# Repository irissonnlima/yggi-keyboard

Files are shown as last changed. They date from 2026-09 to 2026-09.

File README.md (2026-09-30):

<p align="center">Marca do Yggi</p>

# Yggi Keyboard

**Um teclado split ortholinear que vira column stagger com um clique.** Open hardware e open source.

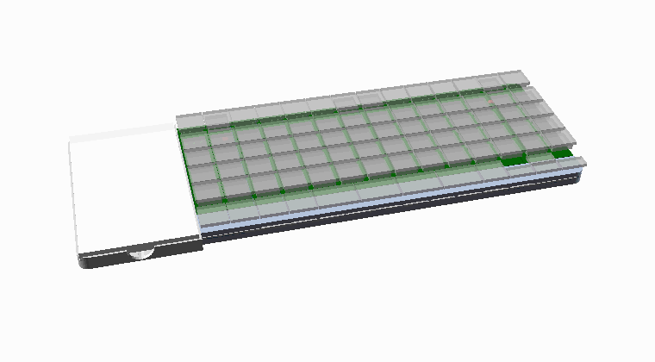
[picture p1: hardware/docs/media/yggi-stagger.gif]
Yggi indo de ortholinear para column stagger


O nome é uma homenagem a Yggdrasil, a árvore que liga os nove mundos da mitologia nórdica. O objetivo de longo prazo é que o Yggi seja o centro que liga os seus computadores e periféricos.

## Conceito de design

> Imagens de conceito para guiar o visual do produto. O projeto técnico (medidas, mecanismo, placas) está em [`hardware/`](hardware/).

**Ortholinear e column stagger.** Em cima, o teclado fechado: um retângulo perfeito, com a baia do e-reader à esquerda. Embaixo, as colunas destravadas e deslizadas no stagger: as colunas externas e a fileira do polegar ficam fixas.

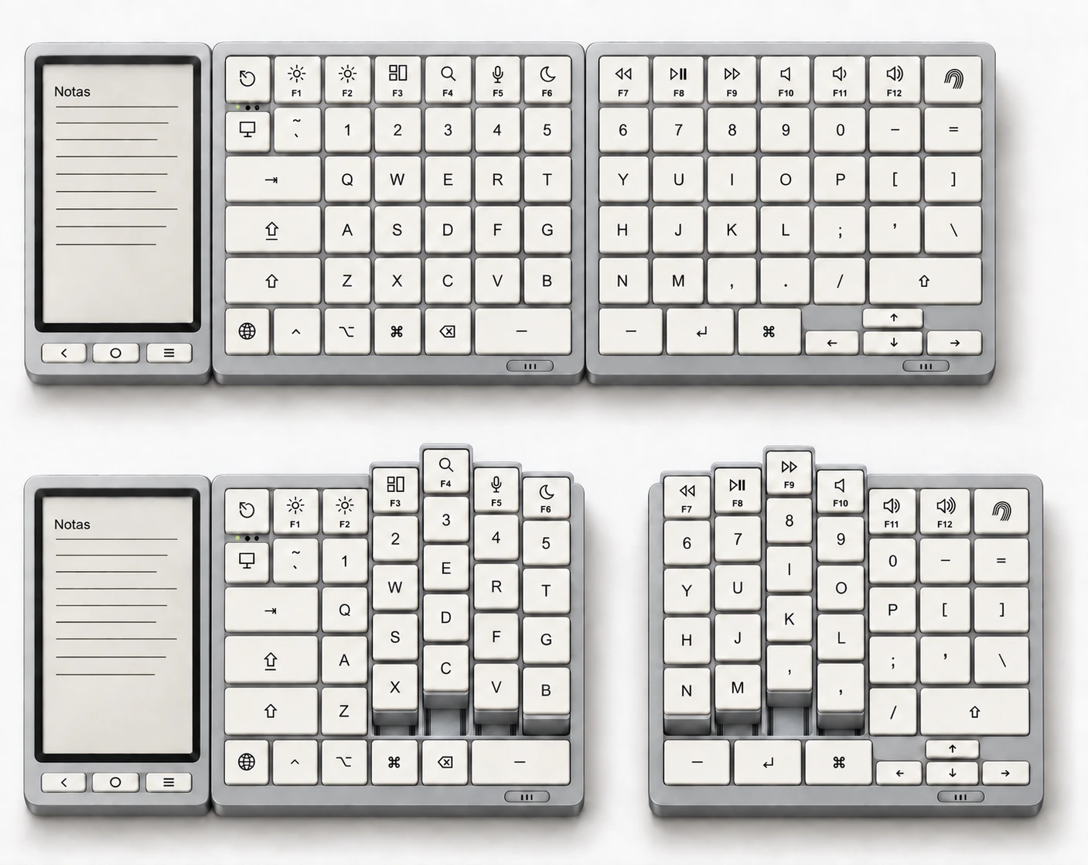
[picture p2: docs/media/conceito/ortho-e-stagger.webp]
Yggi em ortholinear e em column stagger


**Colunas que deslizam inteiras.** Cada coluna corre sobre trilhos, e o vão que ela deixa fica aparente e acabado, sem moldura solta.

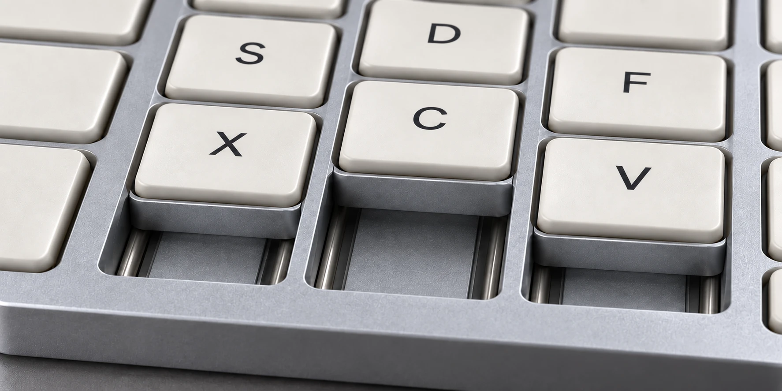
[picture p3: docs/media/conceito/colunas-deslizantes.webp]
Colunas deslizantes sobre trilhos


**E-reader destacável e conectores.** O e-reader tem tela e-ink, três botões, apoio de mesa e USB-C próprio. Ele encaixa na lateral do teclado por uma fileira de contatos pogo, com ímãs acima e abaixo.

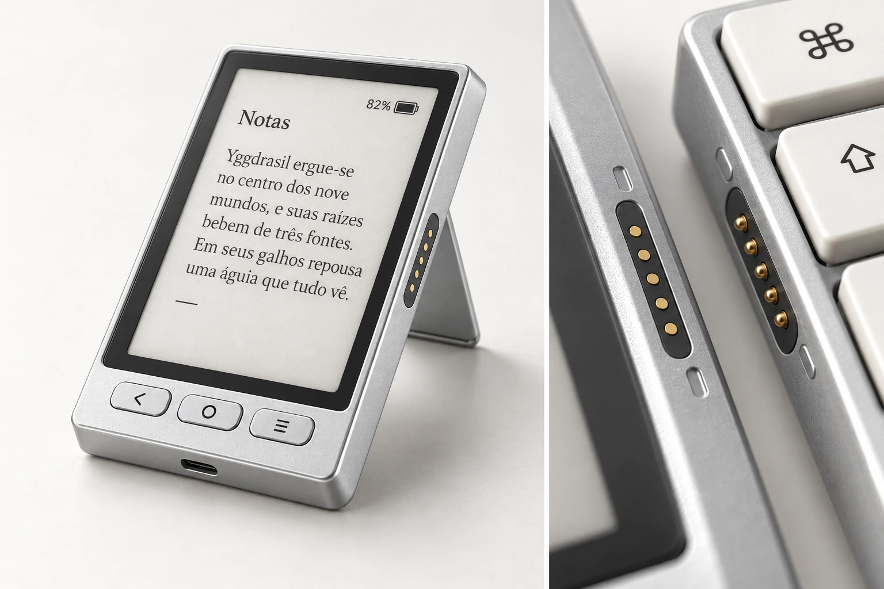
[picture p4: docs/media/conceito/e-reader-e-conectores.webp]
E-reader destacável e conectores pogo


## Marca

Três barrinhas iguais em Y, na simetria isométrica (120° entre elas): os dois braços são as metades do teclado e a haste é o tronco que liga tudo, como a Yggdrasil. Os arquivos estão em [`docs/brand/`](docs/brand/): [marca](docs/brand/yggi-marca.svg), [marca branca](docs/brand/yggi-marca-branca.svg), [assinatura](docs/brand/yggi-assinatura.svg) e [ícone do app](docs/brand/yggi-icone.svg).

Na barra de menus do Mac, o ícone é o próprio teclado em miniatura, visto de cima: as colunas sobem conforme o stagger abre (de 0 a 100%), as metades se afastam quando estão separadas, e o ícone fica apagado quando o teclado está desconectado. Clicar nele abre o balão com os widgets.

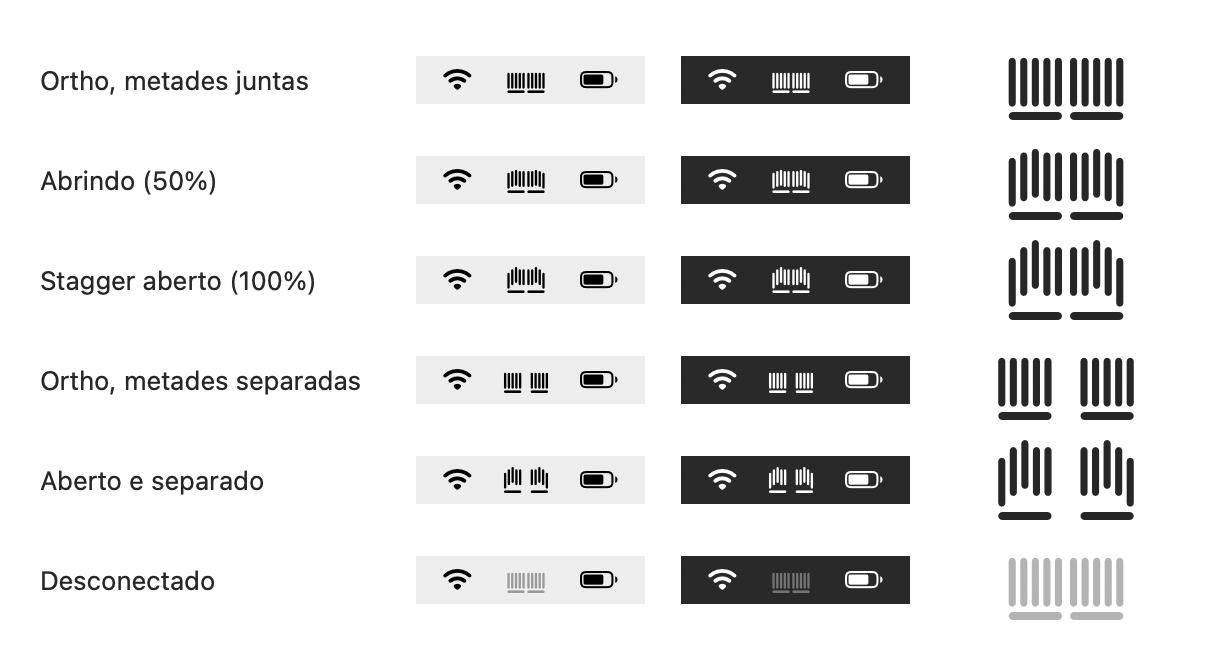
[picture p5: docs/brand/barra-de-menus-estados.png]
Ícone da barra de menus em cada estado


## Onde está cada coisa

| Pasta | O que tem |
|---|---|
| [`hardware/`](hardware/) | mecanismo de stagger (CAD), placas de circuito, layout das teclas, simulação interativa |
| [`app/`](app/) | app do computador: núcleo em Rust + interface macOS em SwiftUI ([como rodar](app/README.md)) |
| [`docs/`](docs/) | documentação do produto: [funcionalidades](docs/funcionalidades.md), [app](docs/app.md), [arquitetura e testes](docs/arquitetura.md), marca e imagens de conceito |

Ainda virá `firmware/` (ZMK + módulos Yggi).

## Fases

1. **Teclado Bluetooth** com o mecanismo de stagger.
2. **E-reader destacável** que encaixa no teclado.
3. **Hub**: mouse, trackpad e áudio passando pelo Yggi.

**[▶ Simulação interativa](https://htmlpreview.github.io/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)**

## Licença

A definir. Sugestão: **CERN-OHL-S-2.0** para o hardware e **MIT** para firmware e software.

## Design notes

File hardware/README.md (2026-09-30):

# Yggi Keyboard · hardware

**Um teclado split ortholinear que vira column stagger com um clique.** Open hardware e open source.

Yggi indo de ortholinear para column stagger

Em ortholinear, as duas metades formam um retângulo perfeito, como um teclado comum. Aperte o botão ao lado dos LEDs e uma mola faz as colunas deslizarem inteiras até o stagger escolhido (50, 100 ou 150%). Para voltar, empurre as colunas até ouvir o clique.

O nome é uma homenagem a Yggdrasil, a árvore que liga os nove mundos da mitologia nórdica. O objetivo de longo prazo é que o Yggi seja o centro que liga os seus computadores e periféricos.

**[▶ Abrir a simulação interativa](https://htmlpreview.github.io/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)** ([arquivo](docs/simulacao.html)): vista de cima com antes e depois, corte lateral, **raio-x dos circuitos** (as 5 placas em cadeia, jumpers, MCU, bateria, USB-C, ímãs e pogo), diagrama das ligações e o ciclo da mola em corte.

---

## Estado atual

| | |
|---|---|
| **Fase** | 1 · teclado Bluetooth com mecanismo de stagger |
| **CAD** | [`stagger-mechanism/yggi_v3.scad`](stagger-mechanism/yggi_v3.scad) (OpenSCAD, paramétrico) |
| **Layout** | [`layout/yggi-v9-B-ortho.json`](layout/yggi-v9-B-ortho.json) (Keyboard Layout Editor) |
| **Verificado** | todas as peças compilam; nenhuma colisão entre peças em 0, 50, 100 e 150% |
| **Ainda não testado** | nada foi impresso ou montado |

| Ortholinear (0%) | Column stagger (150%) |
|---|---|
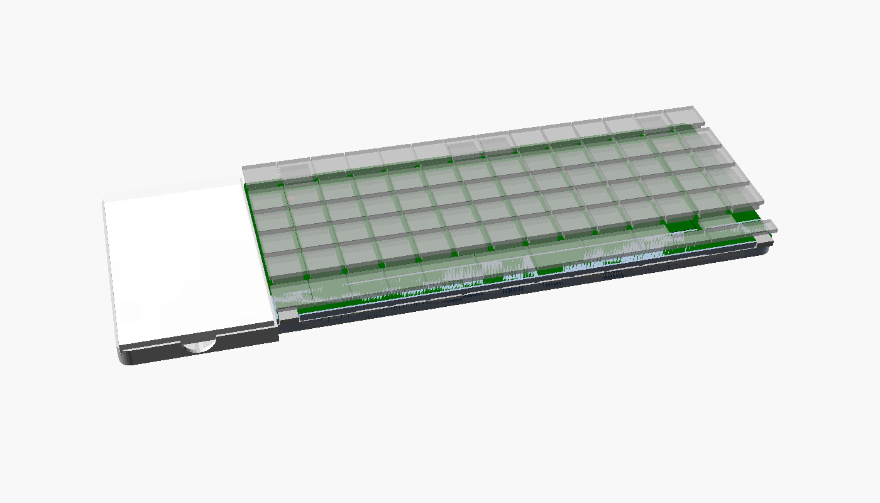
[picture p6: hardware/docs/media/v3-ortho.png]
ortho
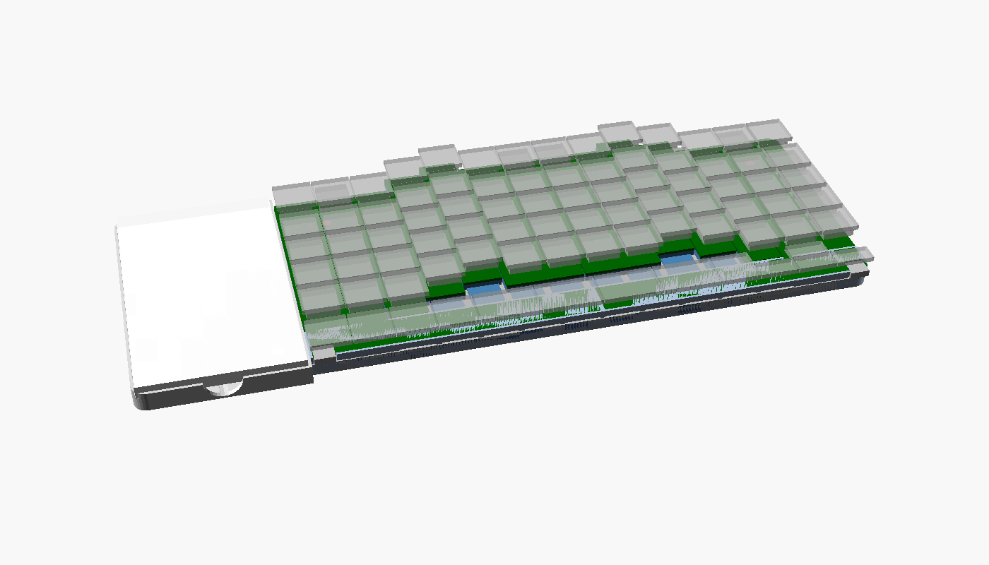
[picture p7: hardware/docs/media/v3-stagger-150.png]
stagger
|  |  |

**Vista lateral** (inclinação de 5° dada pela cunha da bateria):

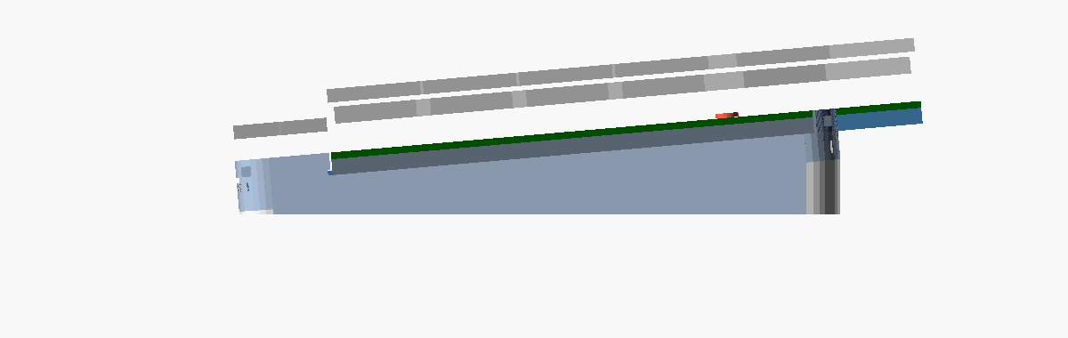
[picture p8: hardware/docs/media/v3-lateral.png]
lateral


**Metade esquerda explodida** (cunha com bateria, bandeja, placa-came, chassi, colunas com as suas placas, bloco fixo, placa L e barra do polegar; na rev1, a placa MCU fica na cunha, ao lado da bateria: veja [`pcb/rev1.md`](pcb/rev1.md)):

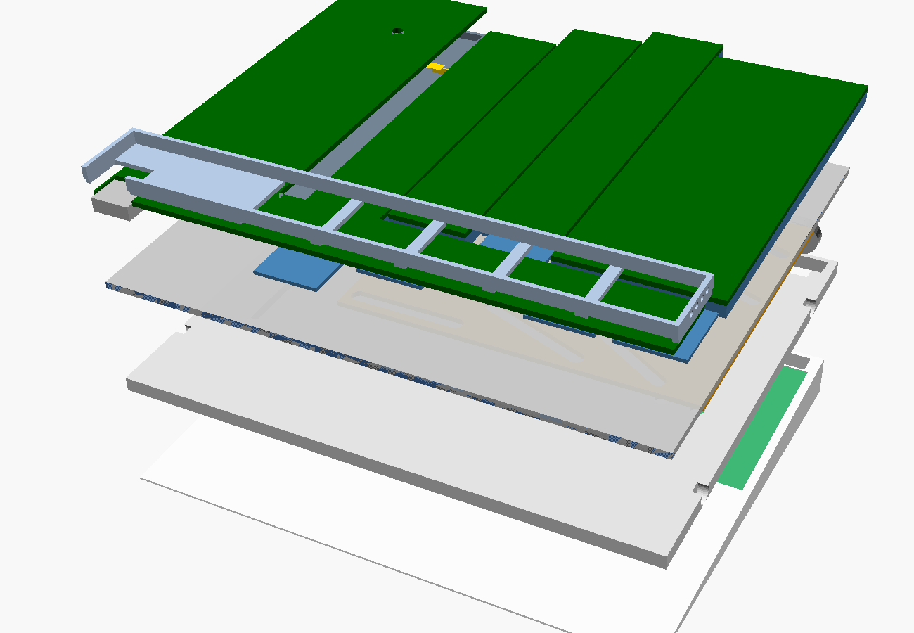
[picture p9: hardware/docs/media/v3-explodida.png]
explodida


**Placas de circuito** ([detalhes](pcb/README.md)): as 6 placas das duas mãos (placa L com o bloco fixo e a barra do polegar, coluna 1u e coluna 2u), geradas com Ergogen e roteadas no KiCad, com LED RGB por tecla:

placas

---

## Layout

Split 7 + 7 colunas com layout Mac, 79 teclas, mais uma baia para um e-reader destacável.

- **2 colunas externas fixas de cada lado:** esc, a **tecla Yggi** (troca de computador) com **3 LEDs** que indicam o aparelho, `` ` ``, e tab, caps e shift de 2u.
- **Colunas móveis:** mindinho, anelar, médio e indicador. Cada uma sobe o quanto o dedo precisa: médio +15 mm, anelar e indicador +9 mm, mindinho 0.
- **Barra do polegar fixa:** fn ⌃ ⌥ ⌘ ⌫ ␣ | ␣ ↩ ⌘ e setas de 0,5u, no estilo Magic Keyboard.
- **Baia de 4u × 6,5u** para um e-reader do tamanho do XTeink X4 (69 × 114 mm).

**Tecla Yggi:** toque vai para o próximo computador pareado. Segurar + 1…5 vai direto para um computador. Segurar 3 s entra em pareamento. A troca só acontece ao soltar a tecla, então um toque acidental não muda nada.

---

## Como o mecanismo funciona

Cada metade, de baixo para cima:

1. **Cunha** (impressa): cria a inclinação de 5° e guarda a **bateria**, o tambor da **mola** e o curso da **trava**.
2. **Bandeja**: bolsão da placa-came, canal da fita da mola e dos fios, lingueta da trava e furos do batente.
3. **Placa-came** (chapa de 1,2 mm): tem 8 rasgos inclinados, 2 por coluna móvel. Ao deslizar 24 mm em X, empurra cada coluna em Y na proporção do rasgo. A posição dos pinos foi escolhida por busca para os rasgos nunca se cruzarem (folga mínima de 9 mm).
4. **Chassi imutável** (chapa de 1,6 mm): rasgos-guia em Y. Fica sempre escondido embaixo das colunas.
5. **Gavetas**: cada coluna móvel é um trenó impresso com **a sua própria placa de circuito** em cima (switches Choc montados direto na placa). As placas se ligam **em cadeia**, de uma coluna para a vizinha, por um jumper flexível que atravessa as paredes na faixa entre a fileira F e a dos números. Dois pinos-parafuso por gaveta fazem o papel de guia, came e trava contra levantar. A **saia** da frente sai de baixo da barra do polegar e tampa o vão quando a coluna sobe.
6. **Bloco fixo** e **barra do polegar**: não se movem.

**Mola e trava:**
- Uma **mola de força constante** (fita de aço, tipo trena) puxa a placa-came para o stagger o tempo todo.
- Em ortho, uma **lingueta** com dente entra num furo da placa e segura tudo.
- O **botão** ao lado dos LEDs empurra o dente para baixo, e a mola leva as colunas até o **pino de batente** (50, 100 ou 150%, trocável por baixo).
- Para voltar, é só empurrar as colunas. Os rasgos são inclinados o bastante (~32°) para o movimento voltar pela came, e o dente estala de volta no furo.

**Módulos:** as faces de encaixe são retas, com ímãs de 4 × 2 mm e um **conector pogo magnético de 5 pinos** (VBUS, GND, 2 de dados e detecção) na face da bandeja. As bordas externas são arredondadas. Com as metades juntas, um único USB-C carrega tudo. Separadas, cada metade funciona sozinha por Bluetooth.

---

## Eletrônica

| | |
|---|---|
| **Placas por metade** | **5, em cadeia**: placa L (bloco fixo + barra do polegar) → coluna 1u → coluna 1u → coluna 1u → coluna 2u. As 3 de 1u são **idênticas**, graças a um barramento rotativo. |
| **Microcontrolador** | um **nRF52840** (módulo Raytac MDBT50Q) por metade, numa **placa MCU própria na cunha**, sob o bloco fixo, com a antena na borda externa. Junto ficam o carregador, a chave dos LEDs e o **USB-C, na face de trás da cunha**. Um flex de 20 vias liga a placa MCU à placa L. Na rev0 das placas, o MCU é externo (nice!nano ligado por fios). Plano: [`pcb/rev1.md`](pcb/rev1.md). |
| **Por que nRF52840** | é o chip mais bem suportado pelo ZMK. Tem 21 GPIO, o suficiente para a matriz 6 × 7 mais os 3 LEDs. |
| **Firmware** | [ZMK](https://zmk.dev) (Zephyr, MIT): Bluetooth, split sem fio, 5 perfis de computador, bateria. Funções do Yggi (tecla de troca, LEDs, conversa com o e-reader) entram como **módulos ZMK** próprios. |
| **Bateria** | LiPo de 4 mm na cunha, ~1800 mAh por metade (76 × 46 mm). A cunha comporta células maiores se a inclinação aumentar. |
| **Ligação das colunas** | **jumper de 13 vias** (5 linhas, 5 colunas, VLED, GND e dados dos LEDs) entre placas vizinhas. Colunas vizinhas andam no máximo 9 mm uma em relação à outra no perfil padrão; o projeto aceita até 15 mm. Protótipo: fios de silicone. Produto: jumper flexível (FPC). |
| **Switches** | Choc V1 com **furos passantes** (soldados ou em soquetes Mill-Max). O soquete hot-swap Kailh não cabe numa coluna de 17,4 mm. As 4 setas de meia altura (mão direita) usam chave tátil SMD (TS-1187A). |
| **Iluminação** | **LED RGB por tecla** (SK6812MINI-E, montado por baixo, brilhando pela janela do Choc): 38 na mão esquerda e 35 na direita, em cadeia de uma placa para a seguinte. Mais os 3 LEDs de aparelho da tecla Yggi. |

O **e-reader** (fase 2) tem cérebro próprio. A base sugerida é o firmware open source [CrossPoint](https://github.com/crosspoint-reader/crosspoint-reader) (ESP32). Encaixado, ele mostra o estado do teclado. Solto, é um leitor.

---

## Estrutura da pasta `hardware/`

```
docs/
  simulacao.html          simulação interativa: vista de cima, corte, raio-x e mola
  media/                  GIF e imagens do README
pcb/
  ergogen/generate.py     gera as placas (Ergogen)
  route.py                termina as placas no KiCad (LEDs, diodos, trilhas pelo Freerouting, DRC)
  assemble.py             junta as 10 placas num arquivo só, para ver o teclado inteiro
  kicad/                  as 6 placas (placa L, coluna 1u, coluna 2u; esquerda e _dir) e teclado_*.kicad_pcb
  outlines/               contornos de corte (.dxf)
stagger-mechanism/
  yggi_v3.scad            CAD atual (mecanismo fino, inclinado, com mola)
  yggi_v2.scad            versão anterior (histórico)
  yggi_stagger.scad       primeiro protótipo, 5 colunas (histórico)
  renders/                imagens geradas pelo OpenSCAD
layout/
  yggi-v9-B-*.json        layout atual para o Keyboard Layout Editor
tools/
  make_gif.py             junta os PNGs do OpenSCAD num GIF (sem dependências)
  pcb_preview.py          prévia SVG das placas a partir dos arquivos do KiCad
```

## Como abrir e gerar

Os comandos abaixo rodam de dentro da pasta `hardware/`.

**CAD:** instale o [OpenSCAD](https://openscad.org) (versão *snapshot*) e abra `yggi_v3.scad`. Em **Window → Customizer** dá para mexer em `stagger_pct`, `stop_pct`, `explode`, `joined` e `show_internals`.

```bash
brew install --cask openscad@snapshot
```

**Exportar uma peça em STL:**

```bash
openscad -D 'part="cam_plate"' -o placa-came.stl stagger-mechanism/yggi_v3.scad
```

**Verificar colisões:** a opção `part="check"` com `check=...` mostra a interseção entre duas peças. Resultado vazio significa sem colisão.

```bash
openscad --backend=manifold -D 'part="check"' -D 'check="gav_chassis"' -D 'stagger_pct=150' -o /tmp/c.stl stagger-mechanism/yggi_v3.scad
```

**Refazer o GIF:**

```bash
for p in 0 25 50 75 100 125 150; do openscad -D "stagger_pct=$p" -D 'stop_pct=150' --camera=90,45,0,55,0,-15,600 --imgsize=760,420 --colorscheme=Tomorrow -o "/tmp/f$p.png" stagger-mechanism/yggi_v3.scad; done
```

```bash
python3 tools/make_gif.py docs/media/yggi-stagger.gif /tmp/f0.png /tmp/f25.png /tmp/f50.png /tmp/f75.png /tmp/f100.png /tmp/f125.png /tmp/f150.png --pingpong
```

---

## Roteiro

1. **Fase 1 · teclado:** imprimir e testar o mecanismo (bandeja, placa-came, chassi e 2 gavetas primeiro), depois firmware ZMK e placas de circuito por gaveta.
2. **Fase 2 · e-reader destacável:** tela, estado do teclado, leitura.
3. **Fase 3 · hub:** mouse, trackpad e áudio passando pelo Yggi.

**Pendências conhecidas:**
- Rev1 da placa L: módulo nRF52840, carregador, USB-C nas duas mãos, chave dos LEDs RGB e **conector pogo magnético de 5 pinos** (VBUS, GND, 2 de dados e detecção), no lugar dos 4 pogo + ímãs soltos.
- Fixação das placas: 1 parafuso M2 por coluna na faixa entre F e números + presilhas no trenó; M2 na placa L.
- Keycap de 0,5u para as setas táteis.
- Estabilizadores das teclas de 2u.
- Escolher a mola de força constante e a bateria reais.
- Testar folgas e a força da trava na prática.

## Licença

A definir. Sugestão: **CERN-OHL-S-2.0** para o hardware e **MIT** para o firmware, a mesma do ZMK.

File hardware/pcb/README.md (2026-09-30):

# Placas de circuito do Yggi (rev0)

Prévia das placas

Cada mão usa **5 placas em cadeia**:

```
placa L  ──►  coluna 1u  ──►  coluna 1u  ──►  coluna 1u  ──►  coluna 2u
(MCU)         (mindinho)      (anelar)        (médio)         (indicador)
```

São **6 projetos** no total, 3 por mão:

| Placa | Esquerda | Direita |
|---|---|---|
| **Placa L** (bloco fixo + barra do polegar, fixa, com o MCU) | esc, Yggi, `` ` ``, tab, caps e shift de 2u; barra com fn, ⌃, ⌥, ⌘, ⌫ e espaço | 8 teclas de 1u (F12, lock, `-`, `=`, `[`, `]`, `'`, `\`) e shift de 2u; barra com espaço, return, ⌘ e 4 setas de meia altura |
| **Coluna 1u** (×3 por mão, **idênticas**) | `coluna_1u` | `coluna_1u_dir` |
| **Coluna 2u** (indicador, fim da cadeia) | `coluna_2u` | `coluna_2u_dir` |

As placas das colunas da direita são as da esquerda com a posição espelhada: a entrada do jumper fica do lado direito. Os switches não são espelhados.

Cada tecla Choc tem um **LED RGB** (SK6812MINI-E). As **setas** da mão direita têm meia altura e o Choc não cabe nelas, então usam uma **chave tátil SMD** (XKB TS-1187A, 5,1 × 5,1 mm) sob um keycap de 0,5u. As setas não têm LED.

As placas saem em duas etapas:
1. O [Ergogen](https://ergogen.xyz) posiciona switches, diodos e pads a partir de [`ergogen/generate.py`](ergogen/generate.py).
2. O [`route.py`](route.py) termina cada placa no KiCad: diodos SOD-123, LEDs RGB, setas táteis, regras da JLCPCB, trilhas pelo [Freerouting](https://github.com/freerouting/freerouting) e DRC.

Os resultados ficam versionados:

| Arquivo | O que é |
|---|---|
| [`kicad/*.kicad_pcb`](kicad/) | as 6 placas roteadas para o KiCad 10, com DRC limpo (0 violações, 0 ligações faltando) |
| [`kicad/teclado_*.kicad_pcb`](kicad/) | **só para ver**: as 10 placas do teclado juntas, na posição do CAD (`teclado_150`: stagger 150%; `teclado_0`: ortho), afastadas para ver onde cada uma acaba. Os jumpers aparecem como linhas de ligação. Gerado por [`assemble.py`](assemble.py) |
| [`kicad/*.kicad_pro`, `*.kicad_dru`](kicad/) | regras de projeto: trilha 0,25, isolamento 0,2, via 0,6/0,3, borda 0,5 mm (0,2 mm só nos pads do LED RGB, que ficam junto do próprio recorte) |
| [`outlines/*.dxf`](outlines/) | contornos de corte, os mesmos usados no CAD |
| [`preview.svg`](preview.svg) | a prévia acima (`python3 hardware/tools/pcb_preview.py`) |

## A ligação em cadeia

Cada placa se liga à vizinha por um **jumper flexível de 13 vias**, que atravessa as paredes das colunas na **faixa livre entre a fileira F e a dos números** (y = 87,25 mm no CAD). É o único corredor sem switches ao longo de toda a coluna.

As colunas vizinhas andam uma em relação à outra quando o stagger muda. Com o perfil padrão em 150%, a diferença é:

| Ligação | Movimento relativo |
|---|---|
| placa L → mindinho | 0 mm |
| mindinho → anelar | 9 mm |
| anelar → médio | 6 mm |
| médio → indicador | 6 mm |

O jumper e os rasgos nas paredes foram dimensionados para **até 15 mm**, então qualquer perfil de placa-came funciona.

- **Protótipo:** 13 fios de silicone 30 AWG, soldados nos pads.
- **Produto:** jumper em placa flexível (FPC) de pé, com 1,6 mm de altura, dobrado em S.

### Barramento rotativo: por que as 3 placas de 1u são iguais

Os dois blocos de pads têm 2 × 7 posições (passo 1,27 mm), na mesma ordem. Dois blocos lado a lado não cabem na coluna de 17,4 mm. Por isso o **J_IN** (entrada) fica 1,6 mm mais para trás e à esquerda, e o **J_OUT** (saída) 1,6 mm mais para a frente e à direita. O jumper liga o J_OUT de uma placa ao J_IN da seguinte, 10,82 mm ao lado. Na mão direita, é o espelho.

| Posição | 1 | 2 | 3 | 4 | 5 | 6 | 7 |
|---|---|---|---|---|---|---|---|
| **J_IN**, linha de cima | R0 | R1 | R2 | R3 | R4 | VLED | GND |
| **J_IN**, linha de baixo | C1 | C2 | C3 | C4 | C5 | — | DIN |
| **J_OUT**, linha de cima | R0 | R1 | R2 | R3 | R4 | VLED | GND |
| **J_OUT**, linha de baixo | C2 | C3 | C4 | C5 | — | — | DOUT |

Cada placa **usa a coluna C1** e repassa as outras deslocadas uma posição. Na placa seguinte, o que era C2 chega como C1, e assim por diante. Por isso a mesma placa serve em qualquer posição da cadeia. A coluna 2u usa C1 e C2 e não tem saída.

Os **dados dos LEDs** entram em DIN, passam pelos LEDs da placa, um depois do outro, e saem em DOUT, na mesma posição do bloco seguinte. VLED e GND passam direto.

### Matriz (uma mão)

**6 linhas × 7 colunas = 13 pinos do MCU**, mais 1 para os LEDs RGB e, na esquerda, 3 para os LEDs da tecla Yggi.

| Linha | Esquerda | Direita |
|---|---|---|
| R0 | fileira F | fileira F |
| R1 | números (inclui a tecla Yggi) | números |
| R2, R3, R4 | letras (tab, caps e shift de 2u em COL0) | letras (shift de 2u em COL0) |
| R5 | barra do polegar (toda na placa L) | barra: espaço COL6, return COL5, ⌘ COL4, ← COL3, ↑ COL2, ↓ COL1, → COL0 |

| Coluna | Onde fica |
|---|---|
| COL0, COL1 | bloco fixo, na placa L |
| COL2 | 1ª placa de 1u (mindinho) |
| COL3 | 2ª placa de 1u (anelar) |
| COL4 | 3ª placa de 1u (médio) |
| COL5, COL6 | placa 2u (indicador) |

Diodos no sentido **COL2ROW**, o padrão do ZMK: coluna → switch → diodo → linha.

### Posição das peças em cada tecla Choc

| Peça | Onde | Face |
|---|---|---|
| LED RGB SK6812MINI-E | 4,7 mm ao sul do centro, na janela do LED do Choc V1, brilhando por um recorte na placa | baixo (montagem invertida) |
| Diodo 1N4148W (SOD-123) | canto noroeste, 3,6 mm à esquerda e 4,5 mm ao norte, na vertical | baixo |

Na barra do polegar os switches ficam girados 180°, e tudo gira junto.

## Decisões e limites da rev0

- **Sem soquete hot-swap Kailh.** O soquete passa ~0,9 mm da borda de uma coluna de 17,4 mm e bateria na parede do trenó. As placas usam os **furos passantes do Choc**: dá para soldar o switch ou usar **soquetes Mill-Max** (tubinhos dentro do furo) e manter a troca de switches.
- **MCU externo na rev0.** Cada placa L tem um **cabeçalho de pads**. Na esquerda são 20: GND, VLED, DIN, R0–R5, COL0–COL6, LED1–3 e GND. Na direita são 17, sem os LEDs da tecla Yggi. Na bancada, ele se liga por fios a uma placa nRF52840 (nice!nano). O VLED vem do VCC chaveado do nice!nano.
- **Na rev1** a eletrônica vai para uma **placa MCU própria na cunha** (módulo nRF52840, carregador, USB-C atrás, chave dos LEDs RGB), ligada à placa L por um flex de 20 vias, mais o conector pogo magnético de 5 pinos, os estabilizadores de 2u e a fixação com M2. Plano completo e posições no CAD: [`rev1.md`](rev1.md).
- **Espessura:** o CAD usa placa de **1,2 mm**. Encomendar com 1,2 mm, ou ajustar `pcb_t` no CAD para 1,6.
- **Trilhas traçadas pelo Freerouting**, em 2 camadas, e conferidas pelo DRC do KiCad. O traçado é automático (funciona, mas não é o mais bonito). O barramento rotativo obriga as trilhas a trocar de face na faixa entre F e números: J_IN e J_OUT têm a mesma ordem, deslocada, e isso não cabe numa face só.
- **LEDs RGB (SK6812MINI-E):** um por tecla Choc, 38 na mão esquerda e 35 na direita. Cuidados:
  - cada LED gasta **~1 mA mesmo apagado** (~75 mA por mão). Por isso a energia deles precisa ser cortada quando estiverem desligados: o VCC chaveado do nice!nano na rev0 e um MOSFET na rev1;
  - em branco total, cada LED puxa até 60 mA, o que dá mais de 2 A por mão. O **brilho precisa ser limitado no firmware**, e as trilhas de 0,25 mm e os fios de 30 AWG do jumper não aguentam o brilho máximo;
  - o SK6812 foi feito para 3,7–5,5 V. No VCC de 3,3 V do nice!nano ele funciona, mas o azul e o branco ficam mais fracos;
  - a posição da janela do LED (4,7 mm ao sul) segue os projetos de referência com Choc V1. **Conferir com um switch na mão** antes de fabricar;
  - os pads do LED ficam a 0,25 mm do canto do recorte, como no footprint oficial do KiCad. O mínimo de borda da placa fica em 0,2 mm, e a regra em `*.kicad_dru` volta a exigir 0,5 mm de todo o resto;
  - um capacitor de 4,7 µF por placa, entre VLED e GND.
- **Setas táteis (direita):** XKB TS-1187A na face de cima, com o diodo embaixo. A altura e o curso são diferentes dos do Choc, então o keycap de 0,5u precisa ser desenhado para elas.
- **Diodos SOD-123 na face de baixo** (1N4148W). O `route.py` troca o diodo do Ergogen, que tem pads nas duas faces e furos passantes, por um SMD simples: fácil de soldar à mão e montável pela JLCPCB.
- **Barra do polegar com os switches girados 180°.** Com o pino 2 virado para trás, o anel dele ficava a 0,28 mm da borda de trás da barra (abaixo do mínimo da JLCPCB). Virado, fica a 0,58 mm da borda da frente. O keycap do Choc é simétrico, então nada muda para quem digita.
- **LEDs da tecla Yggi** (só na esquerda): 3 LEDs 0805 na face de cima, na faixa entre F e números (CAD x = 4, 9 e 14 mm), cada um com um resistor 0805 de 1 kΩ embaixo, no mesmo lugar. Ligação: pino LEDn do MCU → resistor → LED → GND (acende com o pino em nível alto).
- **Furo do botão da trava** (CAD 22; 87,25, espelhado na direita): o `route.py` põe uma área proibida de 2,1 mm de raio em volta dele, e outra em volta de cada recorte de LED RGB, porque o Freerouting não aplica a folga de borda aos recortes internos.
- **Ainda não tem:** furos de fixação (M2 na faixa + presilhas no trenó), os recortes dos estabilizadores de 2u e os pads do flex. Tudo isso entra na rev1 ([`rev1.md`](rev1.md)).

## Como regenerar

Precisa do KiCad 10 (`brew install --cask kicad`), do Java (`brew install openjdk`) e do [Freerouting 2.4.1](https://github.com/freerouting/freerouting/releases) em `~/.local/share/freerouting/` (ou na variável `FREEROUTING`). A partir da raiz do repositório:

```bash
python3 hardware/pcb/ergogen/generate.py
```

```bash
(cd hardware/pcb/ergogen && for d in coluna_1u coluna_2u placa_L coluna_1u_dir coluna_2u_dir placa_L_dir; do npx ergogen@4.2.1 $d.yaml -o output/$d && cp output/$d/outlines/board.dxf ../outlines/$d.dxf; done)
```

```bash
/Applications/KiCad/KiCad.app/Contents/Frameworks/Python.framework/Versions/Current/bin/python3 hardware/pcb/route.py
```

```bash
python3 hardware/pcb/assemble.py && python3 hardware/pcb/assemble.py 0
```

```bash
python3 hardware/tools/pcb_preview.py hardware/pcb/preview.svg hardware/pcb/kicad/placa_L.kicad_pcb hardware/pcb/kicad/coluna_1u.kicad_pcb hardware/pcb/kicad/coluna_2u.kicad_pcb hardware/pcb/kicad/coluna_2u_dir.kicad_pcb hardware/pcb/kicad/coluna_1u_dir.kicad_pcb hardware/pcb/kicad/placa_L_dir.kicad_pcb
```

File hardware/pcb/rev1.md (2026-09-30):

# Rev1 das placas · plano

> **Status:** arquitetura decidida e já refletida no CAD (`yggi_v3.scad`, sem colisões em 0 e 150%). As placas da rev1 ainda não foram desenhadas no KiCad.

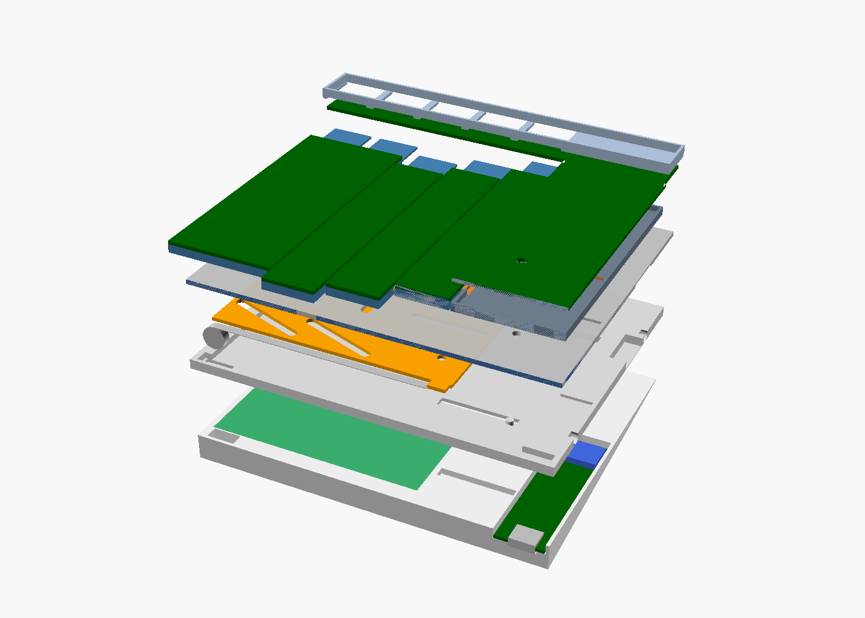
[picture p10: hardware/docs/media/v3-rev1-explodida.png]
Metade esquerda explodida, com a placa MCU na cunha


A rev0 tem as 6 placas roteadas, com LED RGB por tecla e o MCU externo (um nice!nano ligado por fios). A rev1 coloca a eletrônica dentro do teclado, numa **placa MCU própria na cunha**, e resolve a fixação das placas.

## Decisões

| Assunto | Decisão | Por quê |
|---|---|---|
| Teclas de 2u | **com estabilizador** | sem ele, tab, caps e shift balançam nas pontas |
| Onde fica o MCU | **placa MCU própria na cunha**, sob o bloco fixo | com os estabilizadores, a placa L não tem mais lugar para o módulo: entre o estabilizador (x ≈ 6,1) e o switch (x = 18) sobram 2 mm, e embaixo da barra há só 1,8 mm de altura |
| Antena | **na borda externa** da placa MCU, cercada de plástico | melhor que a posição antiga, no meio da placa L. A bateria fica longe (x ≥ 48). Recomendo a placa-came em FR4, não em aço |
| USB-C | **na face de trás da cunha**, direto na placa MCU | é a parte mais alta da cunha (~9 mm), e o USB não precisa passar pelo flex. Na frente da barra, ele batia no pino central do switch do fn |
| Placa L ↔ placa MCU | **flex de 20 vias** (passo 0,5 mm) por um rasgo no bloco fixo, no chassi e na bandeja | as duas placas são fixas. O único corredor livre fica em x < 12,5, antes do bolsão da placa-came |
| Conector entre as mãos e com a baia | **pogo magnético de 5 pinos**, na face da bandeja | a barra tem só 3 mm de altura (z 6–9), e o conector tem ~4 mm. Os 4 pogo antigos saem |
| Fixação | **1 M2 por coluna na faixa entre F e números + presilhas no trenó**; M2 na placa L | ver abaixo |

## Onde fica cada coisa (quadro da metade esquerda do CAD)

| Peça | Posição | Variável no CAD |
|---|---|---|
| Placa MCU (1,0 mm) | x 1,5–18,5; y 46–106,5 (até a face de trás); topo em z −2,5, peças viradas para cima | `MCUB` |
| Raytac MDBT50Q (10,6 × 15,6 × 2,2 mm) | x 1,8–17,4; y 49–59,6, deitado em x, com a **antena na ponta de x = 1,8** | `MOD` |
| USB-C mid-mount | x 4,5–13,5, na borda de trás da placa MCU | `USBC` |
| Rasgo do flex | x 1,5–13; y 68,6–70 (entre a tecla tab e o LED RGB da tecla de números de fora) | `FLEX` |
| Conector magnético (outra mão) | face interna da bandeja, na ponta da barra, centro em y = 9, z 0,3–4,3 | `MAGC`, `MAGC_Y[0]` |
| Conector magnético (baia, só na esquerda) | face externa da bandeja, centro em y = 32,25 | `MAGC_Y[1]` |
| Fios da bateria | canal na cunha, da bateria (x = 48) até a placa MCU | — |

A cunha tem 4,5 mm de altura na frente da placa MCU (y = 46) e 9,3 mm atrás. A placa fica num bolsão de 3,7 mm, aberto na face de trás para o USB-C.

## O que vai em cada placa

**Placa L (rev1):** igual à rev0, trocando o cabeçalho do nice!nano pelos **pads do flex de 20 vias**, e com os furos M2 e os recortes dos estabilizadores. Os 20 sinais do flex:

| Sinais | Quantos |
|---|---|
| R0–R5, COL0–COL6 (matriz) | 13 |
| DIN, VLED, GND (LEDs RGB) | 3 |
| LED1–LED3 (tecla Yggi; na direita ficam livres) | 3 |
| GND extra | 1 |

**Placa MCU (nova, uma por mão):**

```
USB-C VBUS ──►|── VIN ──► carregador (MCP73831, 500 mA) ──► BAT ──► nRF VDDH (REG0 → 3,3 V)
conector VBUS ─────┘                                          └─► load switch ──► VLED (LEDs RGB)
```

- **MDBT50Q** com a área sem cobre da antena (12,4 mm de largura, em todas as camadas) na borda.
- **Sem regulador externo:** o nRF52840 aceita a bateria direto no VDDH (2,5–5,5 V), e o regulador interno gera os 3,3 V.
- **Um USB-C carrega as duas mãos:** o VBUS passa pelo conector magnético. Um diodo Schottky em cada USB-C impede que uma mão alimente o USB-C da outra.
- **LEDs RGB pela bateria (3,5–4,2 V), com load switch e limite de corrente** (ex.: SY6280, EN em 3,3 V): corta os ~75 mA que os LEDs gastam parados e protege as trilhas e o flex. O dado de 3,3 V funciona com o LED em 4,2 V (VIH ≈ 2,9 V).
- Proteção ESD no USB, resistores de 5,1 kΩ nos CC, divisor para medir a bateria, pads de SWD (gravar o bootloader no módulo novo) e de reset, pads da bateria (célula com proteção embutida) e conector do flex.

## Pinos do nRF52840 (por mão)

| Função | Pinos | Esquerda | Direita |
|---|---|---|---|
| Matriz | 6 linhas + 7 colunas | 13 | 13 |
| Dados dos LEDs RGB | 1 | 1 | 1 |
| LEDs da tecla Yggi | 3 | 3 | — |
| Liga/desliga dos LEDs RGB | 1 | 1 | 1 |
| Nível da bateria (analógico) | 1 | 1 | 1 |
| Conector com a outra mão (2 de dados + detecção) | 3 | 3 | 3 |
| Conector da baia (2 de dados + detecção) | 3 | 3 | — |
| **Total de GPIO** (o MDBT50Q tem 48) | | **25** | **19** |

## Conector magnético de 5 pinos

| Pino | Função |
|---|---|
| 1 | VBUS (carga compartilhada) |
| 2 | GND |
| 3 | dados A |
| 4 | dados B |
| 5 | detecção (encaixado ou não) |

Os dados servem para o split com fio quando as mãos estão encaixadas (**confirmar** o suporte atual do ZMK) ou para conversar com o e-reader. O tamanho em `MAGC` (16,5 × 4 × 6 mm) é estimado: **ajustar quando a peça for escolhida**. Os fios vão do conector até a placa MCU por dentro da bandeja e da cunha.

## Fixação

- **Colunas:** 1 parafuso M2 por coluna na faixa entre F e números (a cabeça fica visível no vão entre os keycaps), mais presilhas impressas no trenó que prendem as pontas da placa. Os blocos do jumper vão ceder ~4,5 mm de largura na faixa, então os pads serão reorganizados.
- **Placa L:** M2 nos cantos do bloco fixo e na barra, entre as teclas.
- **Placa MCU:** 2 M2 na cunha.

## Falta fechar

1. **Modelo do estabilizador de 2u** (medidas dos recortes na placa L). As placas da rev0 não têm esses recortes.
2. **Peças exatas na LCSC:** USB-C mid-mount, conector magnético, conector do flex, load switch e diodos. Todas precisam caber nos 3,7 mm do bolsão.
3. **Split com fio pelo conector:** confirmar no ZMK. Se não houver suporte, os 2 pinos de dados ficam para o e-reader e para uso futuro.
4. **Onde prender os fios** do conector magnético até a placa MCU (canal na bandeja).

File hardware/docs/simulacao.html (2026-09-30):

# Yggi Keyboard · simulação

Split ortholinear que vira column stagger. Mecanismo v3: gavetas deslizantes sobre um chassi imutável, placa-came com mola, cunha traseira com bateria e baia para o e-reader.

## 1 · Vista de cima: antes e depois

Arraste o stagger. As 2 colunas externas de cada lado e a barra do polegar não se movem; as outras colunas deslizam inteiras e a saia (tracejada) tampa o vão.

Stagger0% animar

Encaixe do e-readerà esquerdano centroAparelho123

## 2 · Corte lateral: v2 × v3

A v3 fica fina porque a placa de circuito de cada coluna é o próprio plate, e placa-came e chassi são chapas finas. As placas se ligam em cadeia, de coluna em coluna, na faixa entre a fileira F e a dos números. A bateria vai numa cunha atrás e dá a inclinação.

Versãov2v3Stagger

## 3 · Raio-x de cima: circuitos e conexões

Cinco placas por metade, ligadas em cadeia: a placa L (bloco fixo + barra do polegar, com o MCU) → três colunas de 1u idênticas → a coluna dupla do indicador. Cada ligação é um jumper de 10 vias que atravessa as paredes na faixa entre a fileira F e a dos números, e se curva quando as colunas vizinhas andam diferente. Toque numa peça para ver o que é.

colunas (trenós) placas jumpers da cadeia MCU, bateria, USB-C ímãs e pogo placa-came mola e trava

Toque numa peça para ver o nome e a função.

Stagger100%Módulosencaixadosseparados

## 4 · Como os circuitos se ligam

Uma metade do teclado. Setas tracejadas = jumpers que se curvam quando as colunas andam.

## 5 · Mola: soltar e travar

Corte lateral no mesmo estilo da seção 2, passando pela trava. Embaixo, a placa-came vista de cima com a mola. O botão empurra o dente da trava para baixo, a mola puxa a placa e as colunas sobem até o batente. Empurrando as colunas de volta, o dente estala no furo e trava.

apertar o botão empurrar as colunas de volta Batente50%100%150%

Yggi Keyboard · open hardware (CERN-OHL-S sugerida) · CAD em hardware/stagger-mechanism/yggi_v3.scad

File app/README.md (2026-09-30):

# Yggi · app do computador

App do teclado Yggi: estado (computador ativo, baterias, conexão, stagger, e-reader), luzes de cada tecla, estatísticas de digitação e, depois, o editor de teclas. Hoje roda no **macOS**, com um **teclado simulado**, porque o firmware ainda não existe.

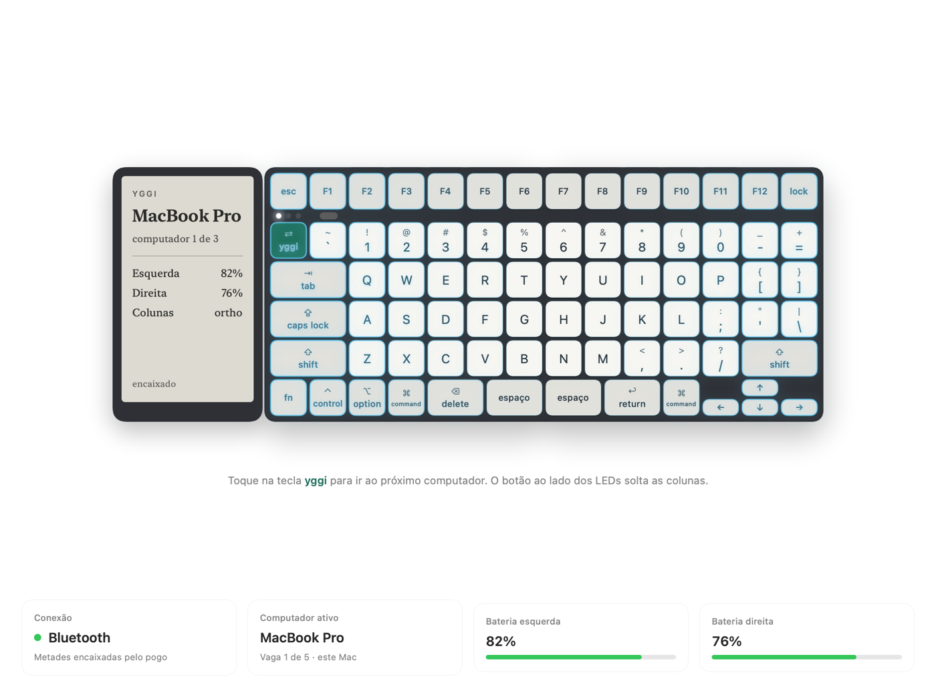
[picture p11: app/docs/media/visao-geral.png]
Visão geral


| Metades separadas, e-reader solto, stagger | Estatísticas (tema escuro) |
|---|---|
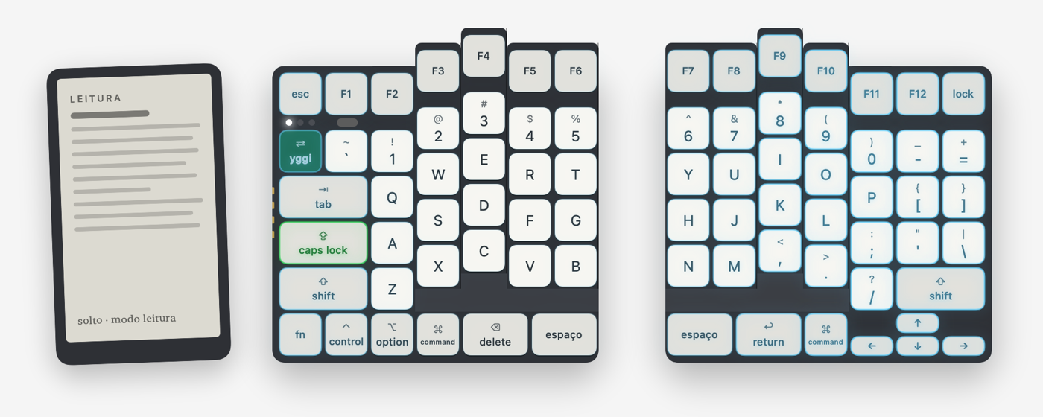
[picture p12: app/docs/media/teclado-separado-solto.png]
teclado
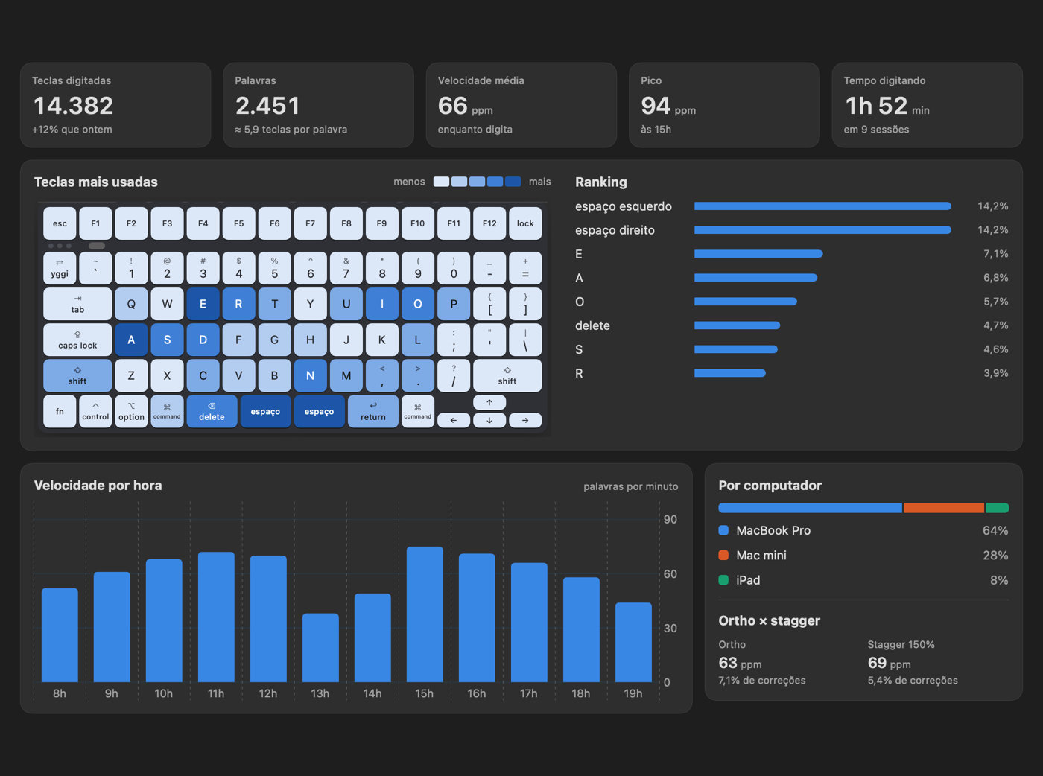
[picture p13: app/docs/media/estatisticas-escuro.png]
estatísticas
|  |  |

Decisões e arquitetura: [docs/app.md](../docs/app.md). Design das telas: [canvas no Claude](https://claude.ai/artifact/6vRzYKWAszEfThTY9fC1pt) (privado; compartilhe pelo menu Share do canvas).

## Telas

| Tela | O que faz |
|---|---|
| **Barra de menus** | baterias, computadores (clique para trocar), conexão, abrir o app, Ajustes |
| **Visão geral** | o teclado desenhado ao vivo: stagger (as colunas sobem com mola), metades juntas ou separadas, e-reader encaixado/solto, LEDs de computador e luzes |
| **Teclas e camadas** | o que cada tecla faz (só leitura até existir o protocolo do ZMK Studio no firmware) |
| **Luzes e efeitos** | LED RGB em cada tecla, em 3 camadas: efeito geral < cores por tecla < teclas de ação |
| **Estatísticas** | teclas, palavras, velocidade, mapa de calor, por computador, ortho × stagger (só contagens, nunca o texto) |
| **Ajustes** (⌘,) | aparência Sistema / Claro / Escuro e opções gerais |

No simulado, o menu **Simulador** da barra de ferramentas faz o que o teclado faria sozinho: cenários (bateria baixa, desconectado…), caps lock, pareamento, cabo USB-C.

## Como está dividido

```
app/
  core/                 núcleo em Rust (yggi-core): toda a lógica, sem interface
    src/model.rs          estado do teclado: conexão, baterias, computadores, stagger, e-reader
    src/layout.rs         onde cada tecla fica e quanto cada coluna sobe no stagger
    src/lighting.rs       luzes: regras (LightingConfig) e LightingEngine, que calcula cada quadro
    src/stats.rs          estatísticas (formato + dados do simulador)
    src/keyboard.rs       interface Keyboard (simulado ou real) e erros
    src/simulator.rs      teclado simulado e seus cenários (+ testes)
    src/session.rs        KeyboardSession: o que as interfaces chamam
  macos/                interface macOS em SwiftUI (só telas)
    Yggi.xcodeproj
    Yggi/                 app: YggiApp, KeyboardStore, Theme
      Views/Keyboard/       o teclado e o e-reader desenhados a partir do layout do núcleo
      Views/Screens/        Visão geral, Teclas, Luzes, Estatísticas
      Views/                barra lateral, barra de menus, Ajustes
    YggiCore/             pacote Swift que embrulha o núcleo (a ponte é gerada)
  scripts/build-core.sh compila o núcleo e gera a ponte Swift (UniFFI)
  Makefile              atalhos: make core, make run, make test…
```

O núcleo não sabe nada de interface. A interface não sabe nada de Bluetooth, simulador ou regras do teclado: ela chama `KeyboardSession`, desenha o `KeyboardState` que recebe e, para as luzes, pede a cada quadro `LightingEngine.frame(...)`, que devolve a cor e a intensidade de cada tecla. O layout das teclas (`yggiLayout()`) e a subida das colunas (`columnLift`) também vêm do núcleo. Para levar o app a Windows ou Linux, reaproveita-se `core/` inteiro e escreve-se só a interface.

## Pré-requisitos

| | Versão testada | Como instalar |
|---|---|---|
| macOS | 14 ou mais novo | |
| Xcode | 16 ou mais novo (testado no 27) | App Store |
| Rust | estável (testado no 1.98) | `curl --proto '=https' --tlsv1.2 -sSf https://sh.rustup.rs \| sh` |

Não precisa de mais nada: o gerador da ponte (UniFFI) é compilado pelo próprio Cargo. Se o `xcode-select` apontar para as Command Line Tools, o `Makefile` usa o Xcode de `/Applications` sozinho.

## Rodar

De dentro da pasta `app/`:

```bash
make run
```

Compila o núcleo, gera a ponte, compila o app, instala em `~/Applications` (o Dock, o Spotlight e o Launchpad acham ele lá) e abre a janela. É um app normal, com ícone no Dock, e também tem o ícone do teclado na barra de menus: clicar abre o balão com os widgets; clique direito tem "Abrir Yggi…", "Ajustes…" e "Sair".

Outros comandos (`make help` lista todos):

| Comando | O que faz |
|---|---|
| `make test` | testes do núcleo (`cargo test`) |
| `make core` | só compila o núcleo e gera a ponte Swift |
| `make xcode` | gera a ponte e abre o projeto no Xcode (depois é só ⌘R) |
| `make snapshots` | desenha telas e estados do teclado em PNG, claro e escuro, em `build/snapshots` (conferência visual; seletores nativos saem como caixas amarelas) |
| `make universal` | núcleo para Apple Silicon e Intel (precisa de `rustup target add x86_64-apple-darwin`) |
| `make clean` | apaga tudo que foi gerado |

**Mexeu no núcleo em Rust?** Rode `make core` (ou `make run`) antes de compilar no Xcode: a ponte Swift e a biblioteca são geradas por esse passo, não pelo Xcode.

## O que é gerado (e não vai para o Git)

| Arquivo | Gerado por |
|---|---|
| `core/target/` | Cargo |
| `macos/YggiCore/YggiCoreFFI.xcframework` | `scripts/build-core.sh`: biblioteca estática + cabeçalho C |
| `macos/YggiCore/Sources/YggiCore/yggi_core.swift` | `scripts/build-core.sh`: ponte Swift do UniFFI |
| `build/` | `xcodebuild` |

## Como a ponte funciona

1. `cargo build` gera `libyggi_core.a` (usada pelo app) e `libyggi_core.dylib` (só para ler os metadados).
2. O `uniffi-bindgen` lê a `.dylib` e escreve `yggi_core.swift` + o cabeçalho C.
3. O `xcodebuild -create-xcframework` junta a biblioteca e o cabeçalho num `.xcframework`.
4. O pacote `YggiCore` expõe tudo ao app como um módulo Swift comum (`import YggiCore`).

No núcleo, o que atravessa a ponte é marcado com `#[uniffi::export]`, `uniffi::Record`, `uniffi::Enum` ou `uniffi::Object`. No Swift, os nomes viram camelCase (`select_host` → `selectHost(index:)`).

Os avisos do núcleo (`StateListener`) chegam de outra thread. O `KeyboardStore` os passa para a thread principal na ordem em que chegaram.

## Próximos passos

1. `BluetoothKeyboard` no núcleo: bateria pelo Battery Service do ZMK; computador ativo, stagger, e-reader, luzes e estatísticas por um serviço Yggi (módulo ZMK, quando o firmware existir).
2. `ZMKStudioClient`: protocolo do ZMK Studio (protobuf por USB ou Bluetooth) para o editor de teclas.
3. Macros e firmware (itens ainda fora da barra lateral).
4. Interfaces para Windows e Linux sobre o mesmo núcleo.

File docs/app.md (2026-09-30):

# Yggi · app do computador

> Decisões e arquitetura. Como compilar e rodar: [app/README.md](../app/README.md).
> Funcionalidades de referência: [funcionalidades.md](funcionalidades.md), seção 2.

## Decisões

| | Decisão |
|---|---|
| ✅ Plataforma | **macOS** primeiro. O núcleo é portável, para Windows e Linux (e iOS) virem depois só com interface nova. |
| ✅ Divisão | **Núcleo em Rust** com toda a lógica + **interface nativa** em cada sistema (SwiftUI no macOS). Ponte gerada pelo **UniFFI**. |
| ✅ Forma no Mac | **app normal** (Dock, Cmd+Tab, janela) com **ícone na barra de menus** que abre o balão de widgets. |
| ✅ Editor de teclas | falar o **protocolo do ZMK Studio** (RPC em protobuf, por USB ou Bluetooth), com editor próprio. Vem depois da tela de estado. |
| ✅ Estatísticas de digitação | tela desenhada e implementada com **dados simulados**. Onde contar de verdade (teclado ou app) ainda está em aberto. |
| ✅ Luzes | **LED RGB em cada tecla** (a luz passa pela legenda), em 3 camadas: efeito geral < cores por tecla < teclas de ação. As regras ficam gravadas no teclado. Os **LEDs de computador** são outra coisa: um por computador, só brancos. |
| ✅ E-reader | aparelho à parte, na **mesma cor do teclado**, que encaixa na lateral esquerda. O teclado funciona sem ele. |
| ✅ Aparência | tema claro e escuro, **seguindo o sistema** por padrão (Ajustes › Aparência). |
| ✅ Design | [canvas no Claude](https://claude.ai/artifact/6vRzYKWAszEfThTY9fC1pt): barra lateral estilo Finder, teclado desenhado à direita. |
| ✅ Firmware | ainda não existe: o núcleo tem um **teclado simulado** atrás da mesma interface que o teclado real vai usar. |
| ✅ Primeira entrega | tela de estado (2.1): computador ativo, bateria das duas metades, conexão, alimentada pelo simulador. |

## Arquitetura

Detalhes, regras, testes e regressões conhecidas em [arquitetura.md](arquitetura.md).

```
 interface (por sistema)             núcleo yggi-core (Rust, igual em todos)
┌──────────────────────────┐        ┌─────────────────────────────────────────┐
│ macOS: SwiftUI           │ chama  │ KeyboardSession                         │
│   barra de menus, janela │ ─────▶ │   state, subscribe, connect,            │
│   KeyboardStore          │        │   disconnect, select_host               │
│                          │ ◀───── │                                         │
│ Windows, Linux: depois   │ avisa  │ Keyboard (interface)                    │
└──────────────────────────┘        │   ├─ Simulator          hoje            │
         ponte: UniFFI              │   ├─ BluetoothKeyboard  depois          │
                                    │   └─ ZMKStudioClient    depois          │
                                    └─────────────────────────────────────────┘
```

**Regra da divisão:** a interface só desenha e repassa cliques. Tudo que seria igual em qualquer sistema fica no núcleo: estado, regras (ex.: o que é bateria baixa), simulador, protocolos, mensagens de erro (em português).

- **Modelo** (`KeyboardState`): conexão (desconectado, conectando, conectado por Bluetooth ou USB), cada metade (alcançável, bateria e se está carregando), computador ativo e as 5 vagas de computador (nome, pareado, se é este computador).
  Também o estado físico: abertura do stagger (0 a 100%), metades juntas ou separadas, e-reader (encaixado, solto, ausente), caps lock e pareamento.
- **Layout** (`yggiLayout`): as 79 teclas, as 8 colunas móveis e quanto cada uma sobe (`columnLift`). As interfaces desenham a partir daqui.
- **Luzes** (`LightingConfig` + `LightingEngine`): a config é o que vai ao teclado; o motor calcula, quadro a quadro, a cor e a intensidade de cada tecla (efeitos, camadas, reação ao toque, onda ao encaixar o e-reader, brilho de 0 a 100%). Todas as interfaces desenham igual.
- **Estatísticas** (`Statistics`): totais, velocidade por hora/dia/semana, contagem por tecla (mapa de calor), divisão por computador, ortho × stagger. Hoje vêm de `simulatedStatistics`.
- **Marca e ícone da barra** (`brand.rs`): a marca do Yggi em cápsulas (`yggiMark`) e o teclado em miniatura (`keyboardGlyph`, `menuBarGlyph`): uma barrinha por coluna, que sobe com o stagger pela mesma curva do layout, as metades se afastam quando separadas, e fica apagado quando desconectado. O ícone do app sai de `docs/brand/yggi-icone.svg` com `swift scripts/make-icons.swift`.
- **No Mac**, o ícone da barra, o balão (`NSPopover`) e as janelas ficam no `AppDelegate` (AppKit); as telas continuam em SwiftUI.
- **Barra de menus** (`MenuBarConfig`, `menubar.rs`): o popover é montado em abas (até 6) com widgets numa grade de 3 colunas. Há 16 widgets (stagger, computadores, bateria, luz, escrita, pausa, atalhos, firmware…), cada um com os tamanhos que aceita entre 1×1, 2×1, 3×1 (deitados), 1×2 (em pé), 2×2 e 3×2. Cada widget tem um desenho para cada formato: pequeno, deitado, em pé e grande.
  O núcleo guarda o catálogo (`widgetCatalog`) e a posição de cada widget (coluna e linha): a grade respeita células vazias. `menuCanPlace` diz se um tamanho cabe numa célula, `widgetFitSize` escolhe o maior tamanho que cabe ali (o widget se ajusta ao espaço), `menuPlaceWidget` põe o widget onde foi solto, `menuMoveWidgetToTab` e `menuAddWidget` sem célula usam o primeiro lugar livre, e `menuCompactTab` tira os buracos. Cada operação devolve uma config nova e ignora pedidos inválidos.
  A config vira texto (`menuBarEncode`/`menuBarDecode`; lê também a versão 1, sem posições, e tolera widgets de versões mais novas). Hoje fica no Mac; quando houver firmware, pode ir para o teclado. No app, "Barra de menus" na janela é o editor: a prévia mostra as células, arrastar mostra onde o widget cai (azul se cabe, vermelho se cobre outro), puxar a borda direita, a de baixo ou o canto de um widget muda o tamanho na hora (`menuResizeWidget`: o tamanho aceito mais perto do puxado, até o máximo do widget e sem cobrir outro), parar sobre uma aba abre ela, a biblioteca fica na coluna da esquerda com os widgets desenhados de verdade no maior tamanho, e soltar nela remove.
- **`Keyboard`**: a interface que o simulador e o teclado real implementam. As interfaces nunca a veem, só `KeyboardSession`.
- **Avisos**: a interface se inscreve com um `StateListener` e recebe cada mudança de estado. O núcleo avisa de qualquer thread; cada interface leva o aviso para a sua thread de tela.
- **Simulador**: cenários prontos (normal, bateria baixa, carregando, metade direita sem sinal, com outro computador, desconectado). Com o tempo passando, a bateria desce 1% a cada 3 s (esquerda) ou 5 s (direita) e sobe no USB. Ele mostra só o que o app veria de verdade: desconectado, não há bateria nem computador ativo.
- **Teclado real** (quando houver firmware): a bateria vem do Battery Service padrão. O ZMK repassa a da metade direita com `SPLIT_BLE_CENTRAL_BATTERY_LEVEL_PROXY`. O computador ativo e os nomes vêm de um serviço Yggi próprio (módulo ZMK). O transporte de bytes é uma interface: `btleplug` por padrão, e um adaptador nativo onde for preciso (ex.: no macOS, um teclado já conectado não anuncia a presença e precisa ser pedido ao CoreBluetooth).
- **Editor**: `ZMKStudioClient` no núcleo, com as mensagens protobuf do ZMK Studio (`prost`), sobre o mesmo transporte.

**Versões:** macOS 14+ (Observation, MenuBarExtra), Swift 6 com checagem estrita de concorrência, Rust edição 2024, UniFFI 0.32.

## Perguntas em aberto

1. **Nomes dos computadores.** Quem guarda o nome ("MacBook trabalho"): o teclado (aparece em qualquer computador e no e-reader) ou o app? O modelo já tem o campo, e o simulador usa nomes fixos.
2. **Computador ativo sem o módulo Yggi.** Só com o ZMK padrão, o Mac sabe apenas se o teclado está com ele. A proposta é o módulo Yggi publicar o perfil ativo, e o simulador já mostra a versão completa.

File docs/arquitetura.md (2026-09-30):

# Arquitetura do app

O app é um **monolito modular**: um núcleo em Rust (`app/core`, crate `yggi-core`) com toda a lógica, e uma casca fina por sistema (hoje só o macOS, em SwiftUI + AppKit) que desenha e repassa gestos. Tudo vive num repositório e num binário, mas com fronteiras que os testes conferem.

```
┌──────────────────────── macOS (app/macos) ─────────────────────────┐
│ AppDelegate       ícone na barra, balão, janelas (AppKit)          │
│ MenuBarIcon       ícone animado que segue o teclado                │
│ KeyboardStore     guarda o último estado e repassa comandos        │
│ Views/…           telas e widgets: só desenham o que o núcleo diz  │
└──────────────────────────────┬─────────────────────────────────────┘
                   ponte UniFFI │ (tipos de valor + KeyboardSession)
┌──────────────────────────────┴───── núcleo (app/core) ─────────────┐
│ fachada    session     o que as interfaces enxergam                │
│ adaptador  simulator   teclado simulado (depois: Bluetooth, ZMK)   │
│ porta      keyboard    o que um teclado oferece (trait Keyboard)   │
│ domínio    lighting · stats · brand   regras puras                 │
│ base       model · layout · menubar   tipos e regras sem estado    │
└─────────────────────────────────────────────────────────────────────┘
```

## Regras

1. **Lógica fica no núcleo.** Se a regra seria igual no Windows ou no Linux, ela é Rust: estado, validação, geometria do teclado, encaixe da grade, desenho da marca e do ícone, formato de gravação. A casca converte unidades em pontos e trata gestos.
2. **Cada módulo só usa as camadas de baixo.** Base não depende de ninguém; domínio só da base; a porta não conhece o simulador; só a sessão junta tudo. `app/core/tests/arquitetura.rs` confere isso no código-fonte e falha se um módulo novo não tiver camada.
3. **Módulos puros não têm estado nem relógio.** `model`, `layout`, `menubar`, `stats` e `brand` não usam travas, threads nem hora. Toda operação da barra de menus recebe a config e devolve outra.
4. **Uma fonte para cada coisa.** A geometria do teclado simplificado sai de `keyboard_shape`, e a marca sai de `yggi_mark`, que um teste compara com os SVGs de `docs/brand/`. Nada de refazer a mesma conta em Swift.
5. **Aviso é erro.** Rust (`clippy -D warnings`, `cargo fmt --check`) e Swift (`SWIFT_TREAT_WARNINGS_AS_ERRORS`).

## Testes

| Onde | O que cobre | Como rodar |
|---|---|---|
| `core/src/*` (`#[cfg(test)]`) | regras de cada módulo, casos de regressão com o nome do bug | `cargo test` |
| `core/src/menubar.rs` | 20 sementes × 300 edições aleatórias sem quebrar a grade nem a gravação | idem |
| `core/tests/arquitetura.rs` | camadas e pureza dos módulos | idem |
| `core/tests/marca.rs` | SVG da marca = desenho do núcleo | idem |
| `macos/Yggi/Verificacoes.swift` | a cola com o macOS (abaixo) | `Yggi --verificar` |
| `macos/Yggi/Snapshots.swift` | desenha telas, widgets e ícones em PNG para olhar | `make snapshots` |

`make test` roda os testes do núcleo e as verificações; `make check` também formato, lint e imagens. O CI (`.github/workflows/app.yml`) roda o mesmo a cada push.

## Regressões que já aconteceram e o que as segura

| Regressão | Causa | Guarda |
|---|---|---|
| Ícone da barra parou de mudar; botões do balão não abriam janelas | `AppDelegate.shared` lia `NSApp.delegate`, que o SwiftUI ocupa com outro objeto | verificação "AppDelegate.shared…" e "o ícone da barra segue o teclado"; ícone isolado em `MenuBarIcon` |
| Janela cortava a barra lateral e a biblioteca | tela mais larga que o mínimo da janela | `MainView.minimumSize` + verificação "toda seção cabe na janela mínima" (já pegou "Luzes e efeitos" pedindo 1204 com mínimo 1100) |
| Janela sempre por cima / em outra mesa; app fora do Dock | `LSUIElement` + `fullScreenAuxiliary`/`moveToActiveSpace` | verificações "janela comum" e "app normal" |
| Mapa de calor com vão entre as metades juntas | geometria refeita em Swift, esquecendo que a metade direita começa em x 12 | `keyboard_shape` no núcleo + teste `metades_juntas_encostam…` |
| Marca do núcleo e SVG podiam divergir | mesmas medidas em dois lugares | `tests/marca.rs` |
| Ids de widgets apagados voltavam depois de reabrir (achado pelo teste aleatório) | `next_id` não era gravado | gravação inclui `next_id`; teste `ids_apagados_nao_voltam…` |
| Dock e Spotlight com o ícone velho | cópias antigas registradas; app só em `build/` | `make install` em `~/Applications`, só essa cópia registrada; verificação do ícone no pacote |
| Avisos passando despercebidos | nada barrava | avisos viram erro no Rust e no Swift |

## O que ainda é fraco

- **O teclado grande (`KeyboardView`) ainda calcula a própria geometria** (carcaça, saia, deslocamento da metade direita). É o mesmo risco do mapa de calor. Próximo passo: estender `keyboard_shape` com carcaça e e-reader e desenhar só a partir dele.
- **Contas de gesto no editor ficam em Swift**: célula sob o cursor (`GridDrop`) e pontos → células ao redimensionar. São conversões de tela, mas a regra "centrar o widget no cursor" poderia ir para o núcleo com teste.
- **`KeyboardStore` junta coisas demais**: estado do teclado, rascunho das luzes, config da barra de menus e navegação. Dá para separar um `MenuBarStore` e um rascunho de luzes.
- **`menubar.rs` passou de 900 linhas**: vale dividir em catálogo, grade, operações e gravação (submódulos, mesma camada).
- **Swift sem alvo de testes do Xcode**: `--verificar` roda dentro do app (como os snapshots) e cobre a cola. Quando a casca crescer, vale um alvo Swift Testing.
- **Estatísticas ainda são de exemplo** (`simulated_statistics`); o motor real de contagem entra com o firmware.

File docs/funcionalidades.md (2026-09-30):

# Yggi · funcionalidades (rascunho)

> **Status:** rascunho para discussão. Nada aqui está decidido até ser marcado como ✅.
> Legenda de fase: **F1** = teclado Bluetooth (primeira versão) · **F2** = e-reader destacável · **F3** = hub (mouse, trackpad, áudio).

## 1. Teclado

| # | Funcionalidade | Fase | Onde roda | Observações |
|---|---|---|---|---|
| 1.1 | Digitação com layout Mac (79 teclas, split 7 + 7) | F1 | firmware | ZMK |
| 1.2 | Camada **fn**: teclas de mídia e funções do Mac na fileira F | F1 | firmware | brilho, Mission Control, Spotlight, ditado, mídia, volume |
| 1.3 | **Tecla Yggi**: trocar de computador | F1 | firmware | toque = próximo; segurar + 1…5 = direto; segurar 3 s = parear; troca ao soltar |
| 1.4 | **3 LEDs** de aparelho ativo | F1 | firmware | também piscam no pareamento e na bateria baixa? |
| 1.5 | Até 5 computadores pareados por Bluetooth | F1 | firmware | limite do ZMK |
| 1.6 | Split sem fio (metades separadas) e com fio (metades encaixadas pelo pogo) | F1 | firmware | detectar se estão encaixadas? |
| 1.7 | Bateria: nível de cada metade, carga pelo USB-C, sono profundo | F1 | firmware | aviso de bateria baixa |
| 1.8 | Stagger mecânico (0–150%) com mola e trava | F1 | mecânica | **saber em que modo está?** (sensor) |
| 1.9 | Remapeamento de teclas e camadas sem regravar firmware | F1 | firmware + app | ZMK Studio já faz isso por USB/Bluetooth |
| 1.10 | Macros | F1/F2 | firmware + app | |

## 2. App no computador (Swift)

| # | Funcionalidade | Fase | Observações |
|---|---|---|---|
| 2.1 | Ver estado: computador ativo, bateria das metades, conexão | F1 | na barra de menus do macOS |
| 2.2 | Editor visual do teclado: remapear teclas, camadas, macros | F1 | falar o protocolo do ZMK Studio ou um próprio |
| 2.3 | Estatísticas de digitação: palavras, ritmo, teclas mais usadas (mapa de calor) | F1/F2 | **sem guardar o texto digitado** |
| 2.4 | Perfis por aplicativo: trocar camada quando muda o app em foco | F2 | o app avisa o teclado |
| 2.5 | Lembretes de pausa e ergonomia (ex.: sugerir mudar o stagger) | F2 | |
| 2.6 | Atualizar o firmware | F1 | DFU por USB ou Bluetooth |
| 2.7 | Coordenar a troca de computador (app em cada máquina) | F3 | ajuda a mover mouse e áudio junto |

## 3. E-reader e tela (depois)

| # | Funcionalidade | Fase |
|---|---|---|
| 3.1 | Mostrar estado do teclado quando encaixado | F2 |
| 3.2 | Leitor de livros quando solto (base: CrossPoint) | F2 |
| 3.3 | Contador de palavras / sessão de escrita na tela | F2 |
| 3.4 | Menu do teclado (tecla Yggi longa abre na tela) | F2 |

## 4. Hub (depois)

| # | Funcionalidade | Fase |
|---|---|---|
| 4.1 | Mouse e trackpad Bluetooth passando pelo Yggi | F3 |
| 4.2 | Fone: áudio e microfone acompanhando o computador ativo | F3 |

## Perguntas em aberto

1. **O app é só para macOS**, ou também iPhone/iPad (para ver bateria, trocar computador)?
2. **Editor de teclas**: usar o **ZMK Studio** (pronto, open source) e o app foca no resto, ou o app tem o próprio editor?
3. **Estatísticas**: contar no teclado (funciona em qualquer computador, sem app) ou no app (mais detalhe, só onde o app está instalado)?
4. **Sensor de stagger**: vale colocar um sensor (ex.: hall) para o teclado saber se está em ortho ou stagger? Permitiria camadas diferentes por modo e mostrar no app.
5. **Perfis por aplicativo** entram na primeira versão?

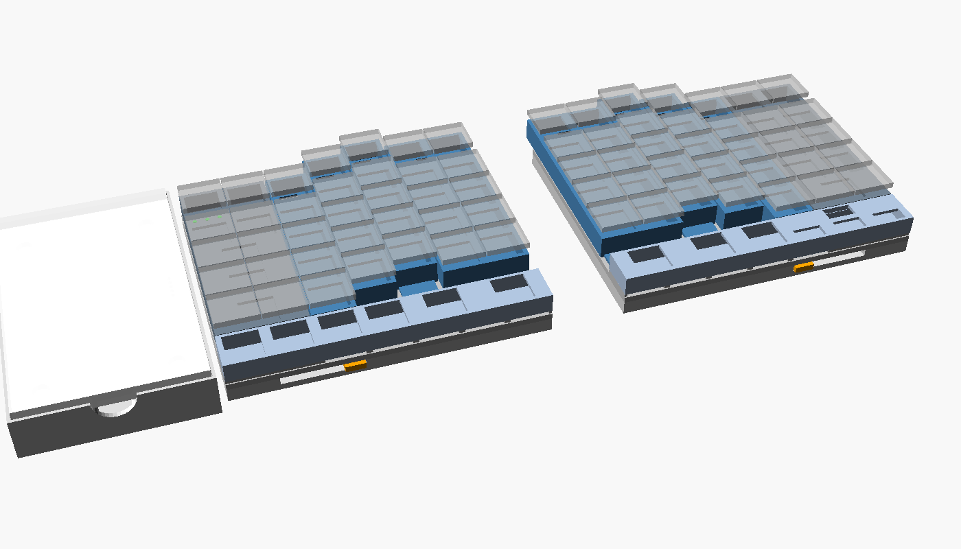
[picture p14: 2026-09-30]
hardware/stagger-mechanism/renders/v2/v2_150pct.png

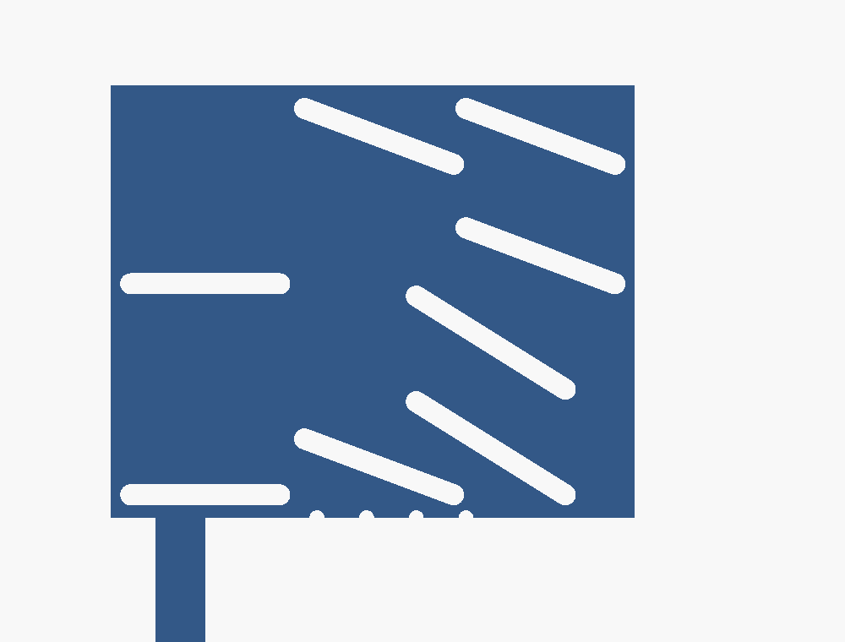
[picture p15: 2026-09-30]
hardware/stagger-mechanism/renders/v2/v2_placa_came.png

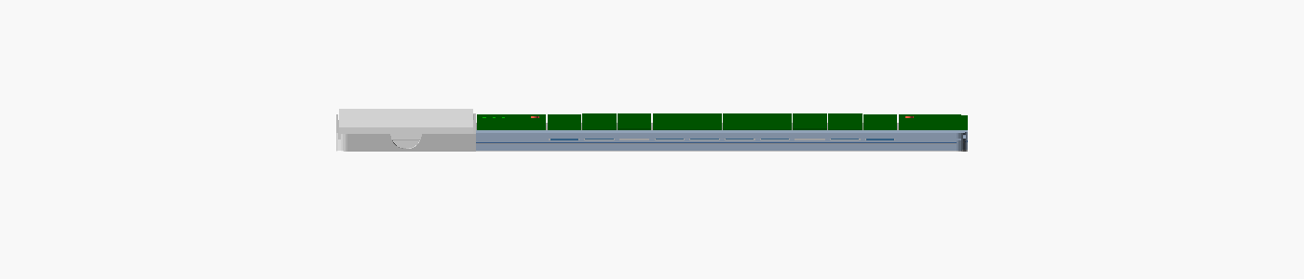
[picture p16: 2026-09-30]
hardware/docs/media/v3-frente.png

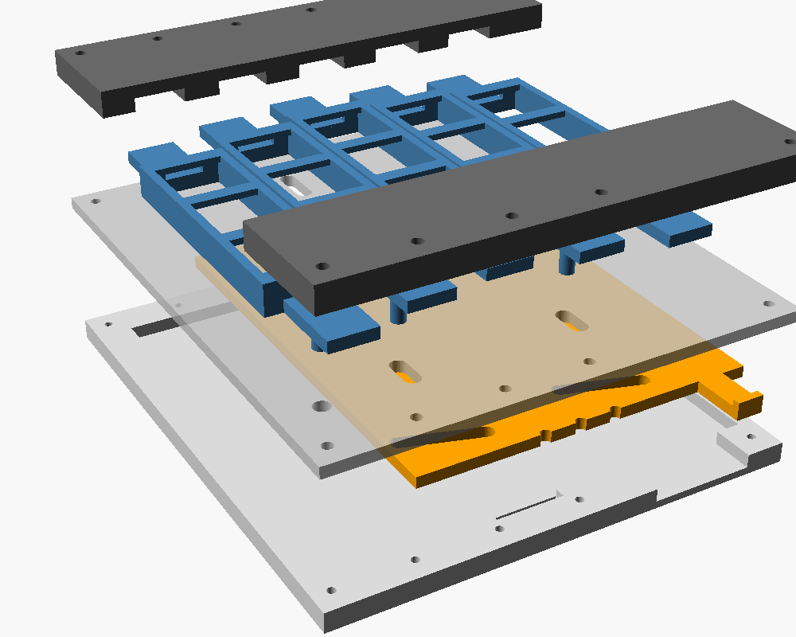
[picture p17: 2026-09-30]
hardware/stagger-mechanism/renders/explodida.png

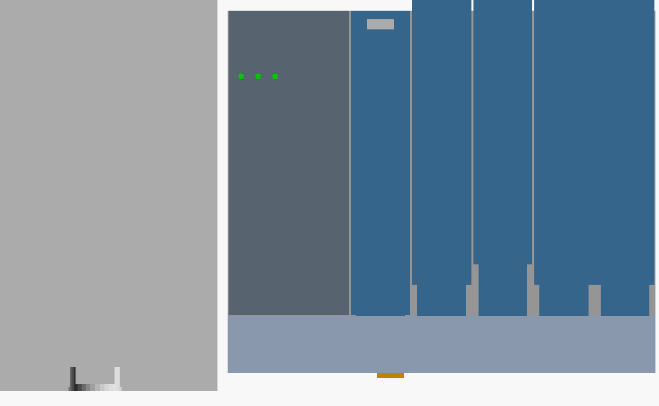
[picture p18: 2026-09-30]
hardware/stagger-mechanism/renders/v2/v2_left_topo_150.png

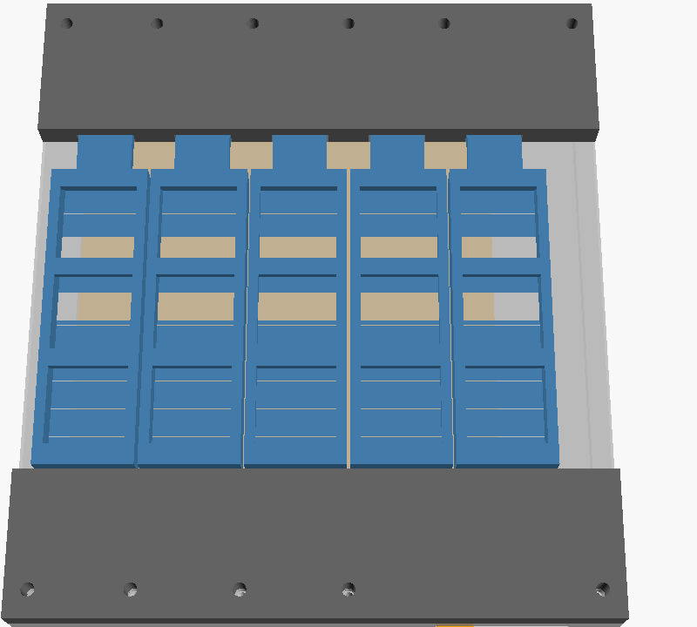
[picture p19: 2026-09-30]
hardware/stagger-mechanism/renders/0pct_ortholinear.png

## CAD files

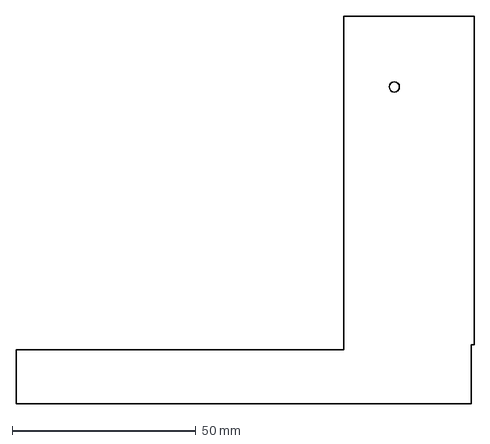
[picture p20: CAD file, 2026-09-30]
hardware/pcb/outlines/placa_L_dir.dxf
124.7 x 105.5 mm

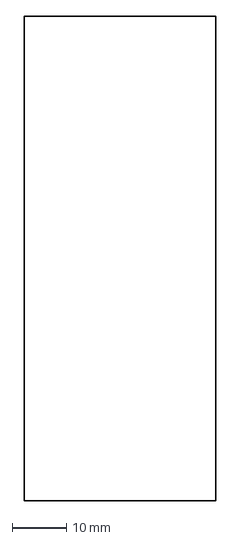
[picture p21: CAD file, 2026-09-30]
hardware/pcb/outlines/coluna_2u_dir.dxf
35.4 x 89.5 mm

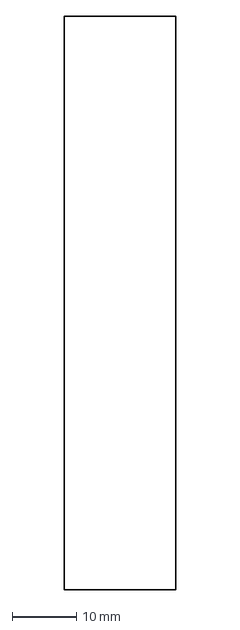
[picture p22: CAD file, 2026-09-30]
hardware/pcb/outlines/coluna_1u_dir.dxf
17.4 x 89.5 mm

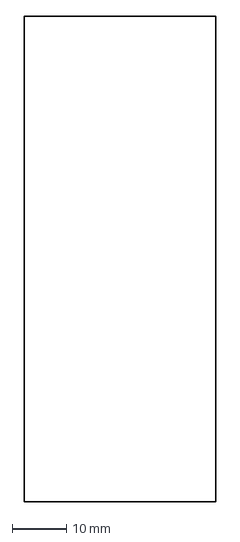
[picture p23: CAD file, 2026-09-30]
hardware/pcb/outlines/coluna_2u.dxf
35.4 x 89.5 mm

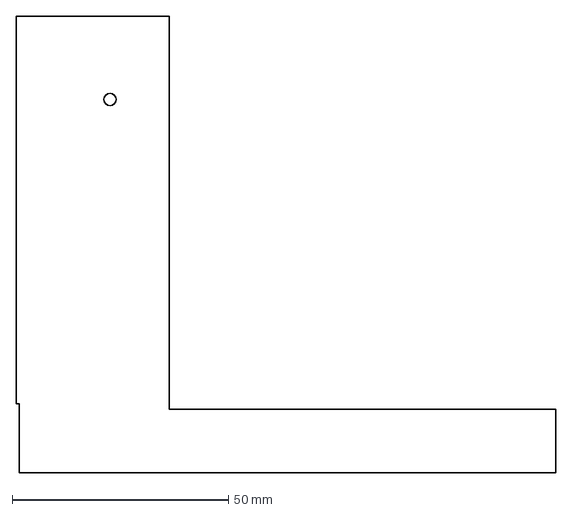
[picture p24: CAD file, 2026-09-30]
hardware/pcb/outlines/placa_L.dxf
124.7 x 105.5 mm

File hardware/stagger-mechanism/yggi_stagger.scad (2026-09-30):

// Yggi Keyboard — mecanismo de stagger ajustável (conceito v0)
// Licença sugerida: CERN-OHL-S-2.0
//
// Princípio: came linear. Uma placa-came desliza em X por baixo das colunas.
// Cada coluna tem um pino que corre num rasgo inclinado da placa. Como a coluna
// só pode andar em Y (presa por linguetas em túneis), empurrar a placa em X faz
// cada coluna subir proporcionalmente à inclinação do seu rasgo.
//   placa em 0%   -> ortholinear
//   placa em 100% -> column stagger completo (perfil = vetor `stagger`)
// Trocar o perfil de stagger = imprimir outra placa-came.
// v1: a placa-came fica inteira dentro da bandeja em qualquer posição. Ela é
// acionada por um cursor que sai pela borda da frente (como a chave de mudo de um celular).
//
// Eixos (mm): X = entre colunas, Y = ao longo da coluna (+Y = longe do usuário), Z = para cima.

/* [Visualização] */
part = "assembly"; // [assembly, tray, cam_plate, base, carrier, tunnel_front, tunnel_back, print_all]
stagger_pct = 100; // [0:1:100]
explode = 0;       // [0:1:20]
show_caps = true;

/* [Layout] */
cols = 5;
rows = 3;
pitch_x = 18;                // espaçamento Choc
pitch_y = 17;
// Deslocamento em Y de cada coluna no modo 100% (mindinho -> indicador interno).
// A coluna 0 é a referência fixa. Valores devem ficar entre 0 e s_max_design.
stagger = [0, 5, 8, 5, 2];
s_max_design = 8;            // curso máximo previsto nos túneis e rasgos da base
travel = 16;                 // curso da placa-came em X

/* [Espessuras e folgas] */
clr = 0.25;
tray_floor = 1.6;
cam_t = 2.5;
base_t = 2.5;
plate_t = 1.3;               // espessura p/ clipe do Choc V1
carrier_h = 6.5;
wall = 1.5;
tongue_w = 10;
tongue_t = 2.5;
tongue_len = 16;
pin_d = 3;
slot_w = pin_d + 0.4;
switch_cut = 13.8;
body_margin = 2;
screw_d = 2.3;               // M2 passante
screw_pilot = 1.8;           // M2 autoatarraxante no plástico
detent_x = 40;
pin_dx = -3.3;               // pino deslocado p/ o lado do mindinho: encolhe o curso total
knob_x = 60;                 // posição do cursor (em 0%) na borda da frente
knob_w = 6;
knob_out = 2;                // quanto o cursor sai da borda (0 = rente)

$fn = 40;

// ---------- Geometria derivada ----------
cw = pitch_x - 0.6;                         // largura do carrinho da coluna
key_len = rows * pitch_y;
body_y0 = -body_margin;
body_y1 = key_len + body_margin;
pin_front_y = body_y0 - 10;
pin_back_y = body_y1 + 12;
tunnel_front_y1 = body_y0 - 0.5;
tunnel_back_y0 = body_y1 + s_max_design + 0.5;
tunnel_h = tongue_t + 0.3 + 2.7;

plate_y0 = pin_front_y - 6;
plate_y1 = pin_back_y + s_max_design + 6;
tray_y0 = plate_y0 - clr - 9.5;
tray_y1 = plate_y1 + clr + 8.5;
tray_x0 = -pitch_x / 2 - 3;
tray_x1 = (cols - 1) * pitch_x + pitch_x / 2 + 10;
tray_h = tray_floor + cam_t + 0.4;

plate_x0 = (1 * pitch_x + pin_dx - travel) - slot_w / 2 - 1;
plate_x1 = (cols - 1) * pitch_x + pin_dx + slot_w / 2 + 1;
pocket_x0 = plate_x0 - clr;
pocket_x1 = plate_x1 + travel + clr;        // a placa anda dentro do bolsão, nunca sai
knob_win = [knob_x - clr, knob_x + knob_w + travel + clr];

screw_front_y = (tray_y0 + plate_y0 - clr) / 2;
screw_back_y = (plate_y1 + clr + tray_y1) / 2;
screw_xs = concat([tray_x0 + 4], [for (i = [0:cols - 2]) (i + 0.5) * pitch_x], [tray_x1 - 4]);
// na frente, pula os parafusos que cairiam na janela do cursor
screw_front_xs = [for (x = screw_xs) if (x < knob_win[0] - 3 || x > knob_win[1] + 3) x];

// Colunas ímpares têm o pino na frente, pares atrás: os rasgos vizinhos não se cruzam.
function pin_front(i) = (i == 0) || (i % 2 == 1);
function pin_y(i) = pin_front(i) ? pin_front_y : pin_back_y;

assert(max(stagger) <= s_max_design && min(stagger) >= 0, "stagger fora do curso previsto");
assert(travel + slot_w < 2 * pitch_x, "rasgos de mesma paridade se cruzam");
assert(pocket_x0 >= tray_x0 + 3 && pocket_x1 <= tray_x1 - 3, "placa-came não cabe dentro da bandeja");
assert(abs(pin_dx) + pin_d / 2 <= tongue_w / 2, "pino fora da lingueta");

// ---------- Peças ----------

module tray() {
    pf = plate_y0 - clr;                    // face frontal do bolsão
    difference() {
        translate([tray_x0, tray_y0, 0]) cube([tray_x1 - tray_x0, tray_y1 - tray_y0, tray_h]);
        // bolsão da placa-came, aberto no lado direito
        translate([pocket_x0, pf, tray_floor])
            cube([pocket_x1 - pocket_x0, plate_y1 - plate_y0 + 2 * clr, tray_h]);
        // janela do cursor na parede da frente
        translate([knob_win[0], tray_y0 - 1, tray_floor])
            cube([knob_win[1] - knob_win[0], pf - tray_y0 + 1.1, tray_h]);
        // mola de trava (flexure): alívio atrás, na ponta, sob e sobre o braço
        translate([detent_x - 12, pf - 2.2, -1]) cube([15, 1, tray_h + 2]);
        translate([detent_x + 2, pf - 2.2, -1]) cube([1, 2.3, tray_h + 2]);
        translate([detent_x - 12, pf - 0.01, -1]) cube([15, 1, tray_floor + 1.01]);
        translate([detent_x - 12, pf - 1.3, tray_h - 0.4]) cube([15, 1.4, 1]);
        for (x = screw_front_xs) translate([x, screw_front_y, 0.8]) cylinder(d = screw_pilot, h = tray_h);
        for (x = screw_xs) translate([x, screw_back_y, 0.8]) cylinder(d = screw_pilot, h = tray_h);
    }
    // dente da trava
    translate([detent_x, pf, tray_floor]) cylinder(r = 1, h = tray_h - tray_floor - 0.4);
}

module cam_plate() {
    difference() {
        translate([plate_x0, plate_y0, 0]) cube([plate_x1 - plate_x0, plate_y1 - plate_y0, cam_t]);
        for (i = [1:cols - 1]) hull() {
            translate([i * pitch_x + pin_dx, pin_y(i), -1]) cylinder(d = slot_w, h = cam_t + 2);
            translate([i * pitch_x + pin_dx - travel, pin_y(i) + stagger[i], -1]) cylinder(d = slot_w, h = cam_t + 2);
        }
        // entalhes da trava: 0%, 50%, 100%
        for (f = [0, 0.5, 1]) translate([detent_x - f * travel, plate_y0, -1]) cylinder(r = 1.2, h = cam_t + 2);
    }
    // cursor: atravessa a parede da frente e sai knob_out mm
    translate([knob_x, tray_y0 - knob_out, 0]) cube([knob_w, plate_y0 - tray_y0 + knob_out + 0.01, cam_t]);
    if (knob_out > 0.5)
        translate([knob_x, tray_y0 - knob_out, cam_t - 0.01]) cube([knob_w, knob_out - 0.3, 1.5]);
}

module base() {
    difference() {
        translate([tray_x0, tray_y0, 0]) cube([tray_x1 - tray_x0, tray_y1 - tray_y0, base_t]);
        // coluna 0: furo redondo (fixa). Demais: rasgo em Y do tamanho do curso.
        translate([pin_dx, pin_y(0), -1]) cylinder(d = pin_d + 2 * clr, h = base_t + 2);
        for (i = [1:cols - 1]) hull() {
            translate([i * pitch_x + pin_dx, pin_y(i), -1]) cylinder(d = slot_w, h = base_t + 2);
            translate([i * pitch_x + pin_dx, pin_y(i) + stagger[i], -1]) cylinder(d = slot_w, h = base_t + 2);
        }
        for (x = screw_front_xs) translate([x, screw_front_y, -1]) cylinder(d = screw_d, h = base_t + 2);
        for (x = screw_xs) translate([x, screw_back_y, -1]) cylinder(d = screw_d, h = base_t + 2);
    }
}

module carrier(i = 1) {
    pin_len = (i == 0) ? base_t - 0.3 : base_t + cam_t - 0.3;
    difference() {
        union() {
            difference() {
                translate([-cw / 2, body_y0, 0]) cube([cw, body_y1 - body_y0, carrier_h]);
                translate([-cw / 2 + wall, body_y0 + wall, -1])
                    cube([cw - 2 * wall, body_y1 - body_y0 - 2 * wall, carrier_h - plate_t + 1]);
            }
            // linguetas que correm nos túneis
            translate([-tongue_w / 2, body_y0 - tongue_len, 0]) cube([tongue_w, tongue_len + wall, tongue_t]);
            translate([-tongue_w / 2, body_y1 - wall, 0]) cube([tongue_w, tongue_len + wall, tongue_t]);
            // pino da came
            translate([pin_dx, pin_y(i), -pin_len]) cylinder(d = pin_d, h = pin_len + 0.01);
        }
        for (r = [0:rows - 1])
            translate([-switch_cut / 2, r * pitch_y + (pitch_y - switch_cut) / 2, carrier_h - plate_t - 1])
                cube([switch_cut, switch_cut, plate_t + 2]);
        // passagem dos fios (laço de serviço) na parede de trás
        translate([-4, body_y1 - wall - 1, tongue_t + 0.5])
            cube([8, wall + 2, carrier_h - plate_t - tongue_t - 0.5]);
    }
}

module tunnel_block(front = true) {
    y0 = front ? tray_y0 : tunnel_back_y0;
    y1 = front ? tunnel_front_y1 : tray_y1;
    cy0 = front ? tray_y0 + 2 : tunnel_back_y0 - 1;
    cy1 = front ? tunnel_front_y1 + 1 : tray_y1 - 2;
    difference() {
        translate([tray_x0, y0, 0]) cube([tray_x1 - tray_x0, y1 - y0, tunnel_h]);
        for (i = [0:cols - 1])
            translate([i * pitch_x - tongue_w / 2 - clr, cy0, -1])
                cube([tongue_w + 2 * clr, cy1 - cy0, tongue_t + 0.3 + 1]);
        for (x = front ? screw_front_xs : screw_xs)
            translate([x, front ? screw_front_y : screw_back_y, -1]) cylinder(d = screw_d, h = tunnel_h + 2);
    }
}

module keycap_ghost() {
    %translate([-17.5 / 2, (pitch_y - 16.5) / 2, 0]) cube([17.5, 16.5, 3]);
}

// ---------- Montagem ----------
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

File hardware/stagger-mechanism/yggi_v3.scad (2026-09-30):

// Yggi Keyboard — mecanismo de stagger v3 (layout B, 7 + 7 colunas + baia do e-reader)
// Licença sugerida: CERN-OHL-S-2.0
//
// O que muda em relação ao v2:
//  - FINO: a placa de circuito de cada gaveta é o próprio "plate" (switch Choc montado na PCB,
//    com soquetes hot-swap embaixo). Placa-came e chassi em chapa fina (FR4 no protótipo).
//  - MOLA: uma mola de força constante puxa a placa-came para o stagger. Em ortho uma trava
//    segura a placa. O botão ao lado dos LEDs empurra a trava e as colunas sobem sozinhas até o
//    batente (50/100/150%). Para voltar, empurra-se as colunas até ouvir o clique.
//  - INCLINAÇÃO: bateria, microcontrolador e mola ficam numa cunha na parte de trás (5°).
//  - MÓDULOS: faces de encaixe retas (ímãs + conector pogo magnético de 5 pinos), bordas externas arredondadas.
//  - ELETRÔNICA (rev1): o microcontrolador fica numa placa própria (placa MCU) na cunha, sob o
//    bloco fixo, com a antena na borda externa e o USB-C na face de trás. Ela se liga à placa L por um
//    flex de 20 vias que atravessa o bloco fixo, o chassi e a bandeja. As teclas de 2u têm estabilizador.
//  - CIRCUITOS EM CADEIA (5 placas por metade): placa L (bloco fixo + barra do polegar,
//    carregador e USB-C) -> coluna 1u -> coluna 1u -> coluna 1u -> coluna dupla. Cada placa se liga
//    à vizinha por um jumper flexível de 13 vias que atravessa as paredes na faixa livre entre a
//    fileira F e a dos números. Barramento rotativo: as 3 placas de 1u são idênticas.
//    Placas geradas com Ergogen em hardware/pcb/.
//
// Eixos (mm): X = entre colunas, Y = ao longo da coluna (+Y = longe do usuário), Z = para cima.
// Tudo é modelado num "quadro plano"; a inclinação é aplicada só na montagem.

/* [Visualização] */
part = "assembly"; // [assembly, left, right, front, tray, cam_plate, chassis, lboard, gaveta, fixed_block, thumb_bar, wedge_left, bay, check]
stagger_pct = 100;  // [0:1:150]
stop_pct = 100;     // [50, 100, 150] batente escolhido
explode = 0;        // [0:1:25]
joined = true;      // metades encostadas (true) ou separadas
show_caps = true;
show_ereader = true;
show_internals = false; // mostra a bateria e a placa MCU na cunha (use com explode)
check = "gav_chassis"; // [gav_chassis, gav_bar, gav_fixed, gav_gav, cam_tray, cam_chassis, heads_tray, pins_cam, pawl_cam, stop_cam, strip_tray, plunger_cam, mcub_parts, lboard_gav, magc]

/* [Grade] */
U = 18;
P = 17;
ROW_Y = [89.5, 68, 51, 34, 17];      // borda frontal de r0 (F) … r4 (shift)

/* [Stagger] */
T = 24;                              // curso da placa-came para 150%
GAV = [                              // [x0, colunas, stagger 150%, pino_x, [pino_y1, pino_y2]]
  [36, 1,  0, 40, [34, 68]],         // mindinho
  [54, 1,  9, 68, [34, 87.25]],      // anelar
  [72, 1, 15, 86, [34, 51]],         // médio
  [90, 2,  9, 94, [68, 87.25]]       // indicador
];

/* [Pilha fina] */
tilt = 5;
clr = 0.25;
side_gap = 0.3;
tray_floor = 1.2;
head_t = 0.6;  head_d = 5;
cam_t = 1.2;                         // FR4 1,2 mm ou aço
chassis_t = 1.6;                     // FR4 1,6 mm
sled_floor = 1.0; sled_wall = 1.0;
sock_h = 1.8;                        // vão sob a placa: pinos do Choc (THT/Mill-Max), diodos SMD, jumper
pcb_t = 1.2;
skirt_t = 0.8; skirt_inset = 1.8;
pin_d = 3;
corner_r = 6;

/* [Bateria e eletrônica] */
BATT = [76, 46, 4.0];                // ~1800 mAh (LiPo 4 mm); ajuste conforme o fornecedor
// Eletrônica na placa L (quadro plano da metade esquerda), pendurada embaixo da placa
// Placa MCU na cunha (quadro plano, abaixo da bandeja): [x, y, largura, comprimento, espessura, z do topo]
// Vai de y 46 até a face de trás (lá a cunha tem ~9 mm). As peças ficam na face de cima (virada
// para a bandeja). x até 18,5: não invade o curso da lingueta (x > 19,5) nem a bateria (x > 48).
MCUB = [1.5, 46, 17, (ROW_Y[0] + P) - 46, 1.0, -2.5];
MOD  = [1.8, 49, 15.6, 10.6, 2.2];   // Raytac MDBT50Q deitado em x: a antena fica na ponta de x = 1,8 (borda externa)
USBC = [4.5, (ROW_Y[0] + P) - 7.3, 9, 7.6, 3.2];   // USB-C mid-mount na face de trás, na borda da placa MCU
// Flex de 20 vias (placa L <-> placa MCU): rasgo no piso do bloco fixo, no chassi e na bandeja. Em
// x < 12,5 (depois disso a bandeja é o bolsão da placa-came); em y entre a tecla tab (termina em 68)
// e o LED RGB da tecla de números da coluna de fora (começa em ~70,3).
FLEX = [1.5, 68.6, 11.5, 1.4];
// Conector pogo magnético de 5 pinos (VBUS, GND, 2 dados, detecção), na face da bandeja:
// [comprimento em y, altura, profundidade] — a confirmar com a peça escolhida
MAGC = [16.5, 4.0, 6.0];
MAGC_Y = [9, 32.25];                 // centro na ponta da barra (outra mão) e na face do bloco fixo (baia)
// Cadeia de placas: pads de 13 vias na faixa entre F e números (y = 87,25)
BAND_Y = (ROW_Y[1] + P + ROW_Y[0]) / 2;
JPAD = [8.62, 2.17];                 // bloco de pads 2 × 7 (passo 1,27): 13 vias (5 linhas, 5 colunas, VLED, GND, DAT)
J_IN_DY = 1.6; J_OUT_DY = -1.6;      // J_IN mais para trás e J_OUT mais para a frente (lado a lado não cabem)
LINK_SLOT = [78, 97];                // rasgo nas paredes para o jumper atravessar
led_d = 1.8;
latch = [22, 87.25];                 // trava + botão (no bloco fixo, entre F e números)

$fn = 32;

// ---------- Derivados ----------
KB_W = 7 * U;
KB_H = ROW_Y[0] + P;
S_MAX = max([for (g = GAV) g[2]]);
skirt_len = S_MAX + 0.5;
slot_w = pin_d + 0.4;
Z_CAM = tray_floor + head_t + 0.2;
tray_h = Z_CAM + cam_t + 0.2;
Z_CH = tray_h;
Z_G = Z_CH + chassis_t;
gav_h = sled_floor + sock_h + pcb_t;
bar_z = Z_G + skirt_t + 0.2;
TOP = Z_G + gav_h;                   // topo das PCBs (base dos switches)
pin_len = Z_G - (tray_floor + 0.05 + head_t);
u = stagger_pct / 150;
t = u * T;
PX = [for (g = GAV) g[3]];
plate_x0 = min(PX) - T - slot_w / 2 - 1.5;
plate_x1 = max(PX) + slot_w / 2 + 1.5;
plate_y0 = min([for (g = GAV) min(g[4])]) - slot_w / 2 - 2;
plate_y1 = max([for (g = GAV) max(g[4]) + g[2]]) + slot_w / 2 + 2;
pocket_x0 = plate_x0 - clr;
pocket_x1 = plate_x1 + T + clr;
ch_y0 = plate_y1 + 0.6;              // canal de trás: fita da mola + fios
ch_y1 = KB_H - 1.2;
drum = [118, (ch_y0 + ch_y1) / 2, 8]; // tambor da mola de força constante (eixo em Y)
stop_x = function (pct) plate_x1 + pct / 150 * T + 1.5 + clr;
BAY_W = 4 * U;  BAY_H = 6.5 * U;
ER = [69, 114, 5.9];                 // XTeink X4
Y_PIV = (KB_H - BAY_H) / 2;          // pivô da inclinação (frente da baia)

function kc(r) = ROW_Y[r] + P / 2;

assert(pocket_x0 >= 3 && pocket_x1 <= KB_W - 3);
assert(latch[0] - 1.5 > plate_x0 && latch[0] < 36 - 3);

// ---------- Utilitários ----------

module fp(round_left = false, w = KB_W, h = KB_H) {       // contorno 2D
    if (round_left) hull() {
        translate([corner_r, corner_r]) circle(r = corner_r);
        translate([corner_r, h - corner_r]) circle(r = corner_r);
        translate([w - 1, 0]) square([1, h]);
    } else square([w, h]);
}
module clip(round_left, z0 = -20, z1 = 40) {
    intersection() { union() children(); translate([0, 0, z0]) linear_extrude(z1 - z0) fp(round_left); }
}
module tilt_frame() { translate([0, Y_PIV, 0]) rotate([tilt, 0, 0]) translate([0, -Y_PIV, 0]) children(); }

// ---------- Gaveta e bloco fixo: trenó impresso + PCB ----------

module sled(x0, n) {
    w = n * U - 2 * side_gap;
    difference() {
        translate([x0 + side_gap, ROW_Y[4], 0]) cube([w, KB_H - ROW_Y[4], sled_floor + sock_h]);
        translate([x0 + side_gap + sled_wall, ROW_Y[4] + sled_wall, sled_floor])
            cube([w - 2 * sled_wall, KB_H - ROW_Y[4] - 2 * sled_wall, sock_h + 1]);
    }
}
module pcb(x0, n) {
    color("darkgreen") translate([x0 + side_gap, ROW_Y[4], sled_floor + sock_h])
        cube([n * U - 2 * side_gap, KB_H - ROW_Y[4], pcb_t]);
}
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

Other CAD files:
hardware/stagger-mechanism/yggi_v2.scad

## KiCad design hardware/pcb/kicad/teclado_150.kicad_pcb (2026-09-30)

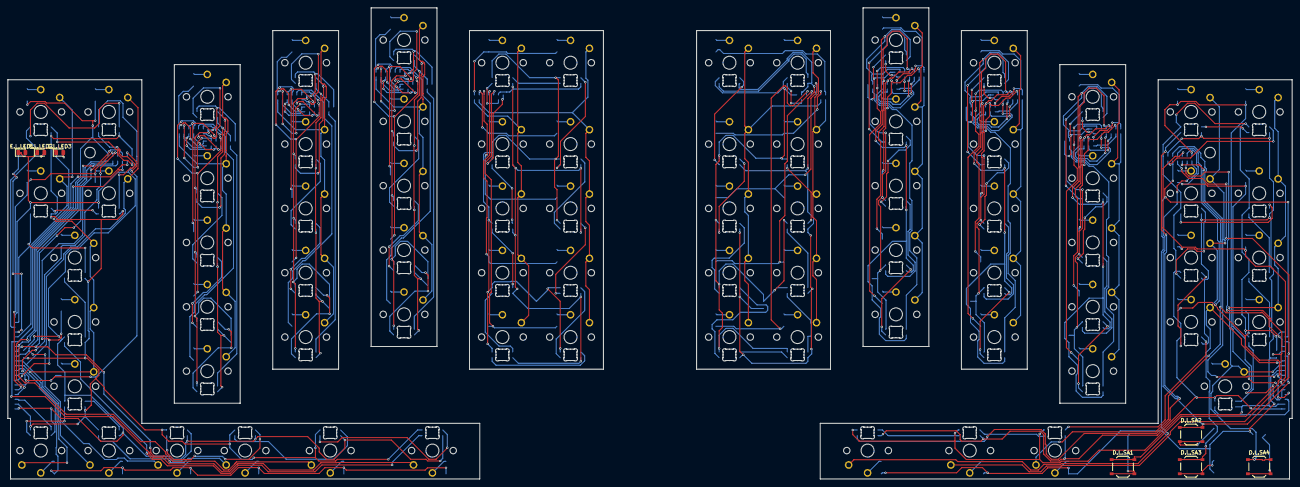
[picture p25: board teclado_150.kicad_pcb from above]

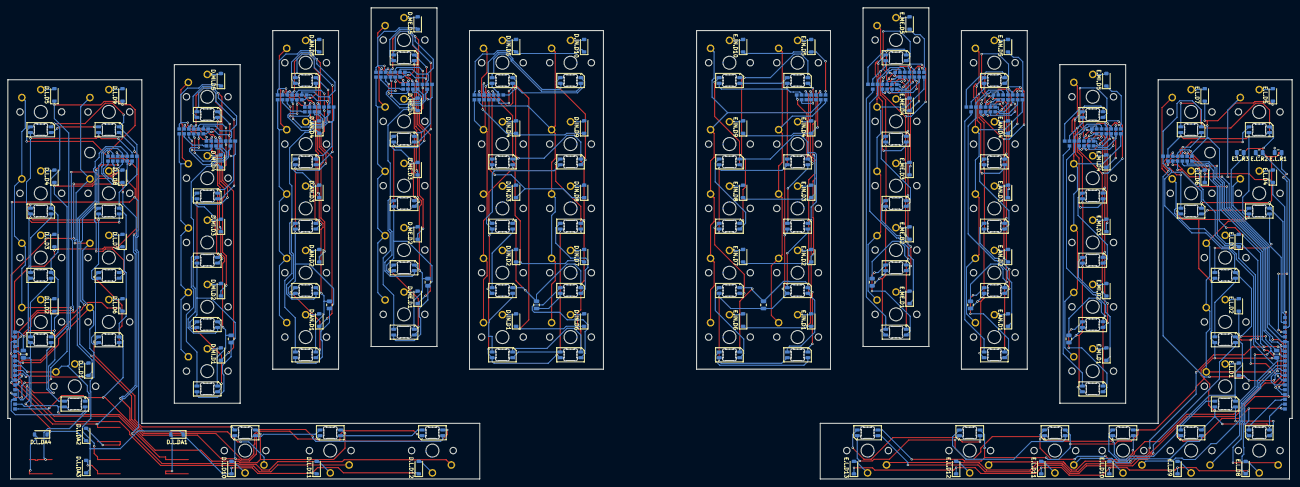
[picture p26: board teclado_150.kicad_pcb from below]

Board: 2 copper layers, 339.4 x 124.5 mm, 488 parts (167 on the bottom side), 196 nets.

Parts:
D.AN.C1, D.IN.C1, D.L.C1, D.ME.C1, D.MI.C1: 4.7uF; C_0805_2012Metric
D.AN.D1, D.AN.D2, D.AN.D3, D.AN.D4, D.AN.D5, D.IN.D1, D.IN.D2, D.IN.D3, D.IN.D4, D.IN.D5, D.IN.D6, D.IN.D7, D.IN.D8, D.IN.D9, D.IN.D10, D.L.D1, D.L.D2, D.L.D3, D.L.D4, D.L.D5, D.L.D6, D.L.D7, D.L.D8, D.L.D9, D.L.D10, D.L.D11, D.L.D12, D.L.DA1, D.L.DA2, D.L.DA3, D.L.DA4, D.ME.D1, D.ME.D2, D.ME.D3, D.ME.D4, D.ME.D5, D.MI.D1, D.MI.D2, D.MI.D3, D.MI.D4, D.MI.D5: 1N4148W; D_SOD-123
D.AN.L1, D.AN.L2, D.AN.L3, D.AN.L4, D.AN.L5, D.IN.L1, D.IN.L2, D.IN.L3, D.IN.L4, D.IN.L5, D.IN.L6, D.IN.L7, D.IN.L8, D.IN.L9, D.IN.L10, D.L.L1, D.L.L2, D.L.L3, D.L.L4, D.L.L5, D.L.L6, D.L.L7, D.L.L8, D.L.L9, D.L.L10, D.L.L11, D.L.L12, D.ME.L1, D.ME.L2, D.ME.L3, D.ME.L4, D.ME.L5, D.MI.L1, D.MI.L2, D.MI.L3, D.MI.L4, D.MI.L5: SK6812MINI-E; LED_SK6812MINI-E_3.2x2.8mm_P1.5mm_ReverseMount
D.AN.PAD1, D.AN.PAD2, D.AN.PAD3, D.AN.PAD4, D.AN.PAD5, D.AN.PAD6, D.AN.PAD7, D.AN.PAD8, D.AN.PAD9, D.AN.PAD10, D.AN.PAD11, D.AN.PAD12, D.AN.PAD13, D.AN.PAD14, D.AN.PAD15, D.AN.PAD16, D.AN.PAD17, D.AN.PAD18, D.AN.PAD19, D.AN.PAD20, D.AN.PAD21, D.AN.PAD22, D.AN.PAD23, D.AN.PAD24, D.AN.PAD25, D.IN.PAD1, D.IN.PAD2, D.IN.PAD3, D.IN.PAD4, D.IN.PAD5, D.IN.PAD6, D.IN.PAD7, D.IN.PAD8, D.IN.PAD9, D.IN.PAD10, D.IN.PAD11, D.IN.PAD12, D.IN.PAD13, D.L.PAD1, D.L.PAD2, D.L.PAD3, D.L.PAD4, D.L.PAD5, D.L.PAD6, D.L.PAD7, D.L.PAD8, D.L.PAD9, D.L.PAD10, D.L.PAD11, D.L.PAD12, D.L.PAD13, D.L.PAD14, D.L.PAD15, D.L.PAD16, D.L.PAD17, D.L.PAD18, D.L.PAD19, D.L.PAD20, D.L.PAD21, D.L.PAD22, D.L.PAD23, D.L.PAD24, D.L.PAD25, D.L.PAD26, D.L.PAD27, D.L.PAD28, D.L.PAD29, D.L.PAD30, D.ME.PAD1, D.ME.PAD2, D.ME.PAD3, D.ME.PAD4, D.ME.PAD5, D.ME.PAD6, D.ME.PAD7, D.ME.PAD8, D.ME.PAD9, D.ME.PAD10, D.ME.PAD11, D.ME.PAD12, D.ME.PAD13, D.ME.PAD14, D.ME.PAD15, D.ME.PAD16, D.ME.PAD17, D.ME.PAD18, D.ME.PAD19, D.ME.PAD20, D.ME.PAD21, D.ME.PAD22, D.ME.PAD23, D.ME.PAD24, D.ME.PAD25, D.MI.PAD1, D.MI.PAD2, D.MI.PAD3, D.MI.PAD4, D.MI.PAD5, D.MI.PAD6, D.MI.PAD7, D.MI.PAD8, D.MI.PAD9, D.MI.PAD10, D.MI.PAD11, D.MI.PAD12, D.MI.PAD13, D.MI.PAD14, D.MI.PAD15, D.MI.PAD16, D.MI.PAD17, D.MI.PAD18, D.MI.PAD19, D.MI.PAD20, D.MI.PAD21, D.MI.PAD22, D.MI.PAD23, D.MI.PAD24, D.MI.PAD25: SMDPad
D.AN.S1, D.AN.S2, D.AN.S3, D.AN.S4, D.AN.S5, D.IN.S1, D.IN.S2, D.IN.S3, D.IN.S4, D.IN.S5, D.IN.S6, D.IN.S7, D.IN.S8, D.IN.S9, D.IN.S10, D.L.S1, D.L.S2, D.L.S3, D.L.S4, D.L.S5, D.L.S6, D.L.S7, D.L.S8, D.L.S9, D.L.S10, D.L.S11, D.L.S12, D.ME.S1, D.ME.S2, D.ME.S3, D.ME.S4, D.ME.S5, D.MI.S1, D.MI.S2, D.MI.S3, D.MI.S4, D.MI.S5: PG1350
D.L.SA1, D.L.SA2, D.L.SA3, D.L.SA4: TS-1187A; SW_Push_1P1T_XKB_TS-1187A
E.AN.C1, E.IN.C1, E.L.C1, E.ME.C1, E.MI.C1: 4.7uF; C_0805_2012Metric
E.AN.D1, E.AN.D2, E.AN.D3, E.AN.D4, E.AN.D5, E.IN.D1, E.IN.D2, E.IN.D3, E.IN.D4, E.IN.D5, E.IN.D6, E.IN.D7, E.IN.D8, E.IN.D9, E.IN.D10, E.L.D1, E.L.D2, E.L.D3, E.L.D4, E.L.D5, E.L.D6, E.L.D7, E.L.D8, E.L.D9, E.L.D10, E.L.D11, E.L.D12, E.L.D13, E.ME.D1, E.ME.D2, E.ME.D3, E.ME.D4, E.ME.D5, E.MI.D1, E.MI.D2, E.MI.D3, E.MI.D4, E.MI.D5: 1N4148W; D_SOD-123
E.AN.L1, E.AN.L2, E.AN.L3, E.AN.L4, E.AN.L5, E.IN.L1, E.IN.L2, E.IN.L3, E.IN.L4, E.IN.L5, E.IN.L6, E.IN.L7, E.IN.L8, E.IN.L9, E.IN.L10, E.L.L1, E.L.L2, E.L.L3, E.L.L4, E.L.L5, E.L.L6, E.L.L7, E.L.L8, E.L.L9, E.L.L10, E.L.L11, E.L.L12, E.L.L13, E.ME.L1, E.ME.L2, E.ME.L3, E.ME.L4, E.ME.L5, E.MI.L1, E.MI.L2, E.MI.L3, E.MI.L4, E.MI.L5: SK6812MINI-E; LED_SK6812MINI-E_3.2x2.8mm_P1.5mm_ReverseMount
E.AN.PAD1, E.AN.PAD2, E.AN.PAD3, E.AN.PAD4, E.AN.PAD5, E.AN.PAD6, E.AN.PAD7, E.AN.PAD8, E.AN.PAD9, E.AN.PAD10, E.AN.PAD11, E.AN.PAD12, E.AN.PAD13, E.AN.PAD14, E.AN.PAD15, E.AN.PAD16, E.AN.PAD17, E.AN.PAD18, E.AN.PAD19, E.AN.PAD20, E.AN.PAD21, E.AN.PAD22, E.AN.PAD23, E.AN.PAD24, E.AN.PAD25, E.IN.PAD1, E.IN.PAD2, E.IN.PAD3, E.IN.PAD4, E.IN.PAD5, E.IN.PAD6, E.IN.PAD7, E.IN.PAD8, E.IN.PAD9, E.IN.PAD10, E.IN.PAD11, E.IN.PAD12, E.IN.PAD13, E.L.PAD1, E.L.PAD2, E.L.PAD3, E.L.PAD4, E.L.PAD5, E.L.PAD6, E.L.PAD7, E.L.PAD8, E.L.PAD9, E.L.PAD10, E.L.PAD11, E.L.PAD12, E.L.PAD13, E.L.PAD14, E.L.PAD15, E.L.PAD16, E.L.PAD17, E.L.PAD18, E.L.PAD19, E.L.PAD20, E.L.PAD21, E.L.PAD22, E.L.PAD23, E.L.PAD24, E.L.PAD25, E.L.PAD26, E.L.PAD27, E.L.PAD28, E.L.PAD29, E.L.PAD30, E.L.PAD31, E.L.PAD32, E.L.PAD33, E.ME.PAD1, E.ME.PAD2, E.ME.PAD3, E.ME.PAD4, E.ME.PAD5, E.ME.PAD6, E.ME.PAD7, E.ME.PAD8, E.ME.PAD9, E.ME.PAD10, E.ME.PAD11, E.ME.PAD12, E.ME.PAD13, E.ME.PAD14, E.ME.PAD15, E.ME.PAD16, E.ME.PAD17, E.ME.PAD18, E.ME.PAD19, E.ME.PAD20, E.ME.PAD21, E.ME.PAD22, E.ME.PAD23, E.ME.PAD24, E.ME.PAD25, E.MI.PAD1, E.MI.PAD2, E.MI.PAD3, E.MI.PAD4, E.MI.PAD5, E.MI.PAD6, E.MI.PAD7, E.MI.PAD8, E.MI.PAD9, E.MI.PAD10, E.MI.PAD11, E.MI.PAD12, E.MI.PAD13, E.MI.PAD14, E.MI.PAD15, E.MI.PAD16, E.MI.PAD17, E.MI.PAD18, E.MI.PAD19, E.MI.PAD20, E.MI.PAD21, E.MI.PAD22, E.MI.PAD23, E.MI.PAD24, E.MI.PAD25: SMDPad
E.AN.S1, E.AN.S2, E.AN.S3, E.AN.S4, E.AN.S5, E.IN.S1, E.IN.S2, E.IN.S3, E.IN.S4, E.IN.S5, E.IN.S6, E.IN.S7, E.IN.S8, E.IN.S9, E.IN.S10, E.L.S1, E.L.S2, E.L.S3, E.L.S4, E.L.S5, E.L.S6, E.L.S7, E.L.S8, E.L.S9, E.L.S10, E.L.S11, E.L.S12, E.L.S13, E.ME.S1, E.ME.S2, E.ME.S3, E.ME.S4, E.ME.S5, E.MI.S1, E.MI.S2, E.MI.S3, E.MI.S4, E.MI.S5: PG1350
E.L.LED1, E.L.LED2, E.L.LED3: LED 0805; LED_0805_2012Metric
E.L.R1, E.L.R2, E.L.R3: 1k; R_0805_2012Metric

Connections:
D.AN.c1_r0: D.AN.D5.2, D.AN.S5.2
D.AN.c1_r1: D.AN.D4.2, D.AN.S4.2
D.AN.c1_r2: D.AN.D3.2, D.AN.S3.2
D.AN.c1_r3: D.AN.D2.2, D.AN.S2.2
D.AN.c1_r4: D.AN.D1.2, D.AN.S1.2
D.AN.livre.C5: D.AN.PAD12.1, D.AN.PAD24.1
D.AN.rgb1: D.AN.L1.4, D.AN.L2.2
D.AN.rgb2: D.AN.L2.4, D.AN.L3.2
D.AN.rgb3: D.AN.L3.4, D.AN.L4.2
D.AN.rgb4: D.AN.L4.4, D.AN.L5.2
D.COL0: D.L.PAD23.1, D.L.S1.1, D.L.S2.1, D.L.S3.1, D.L.S4.1, D.L.S5.1, D.L.SA4.1
D.COL1: D.L.PAD24.1, D.L.S6.1, D.L.S7.1, D.L.S8.1, D.L.S9.1, D.L.SA3.1
D.COL2: D.L.PAD8.1, D.L.PAD25.1, D.L.SA2.1, D.MI.PAD8.1, D.MI.S1.1, D.MI.S2.1, D.MI.S3.1, D.MI.S4.1, D.MI.S5.1
D.COL3: D.AN.PAD8.1, D.AN.S1.1, D.AN.S2.1, D.AN.S3.1, D.AN.S4.1, D.AN.S5.1, D.L.PAD9.1, D.L.PAD26.1, D.L.SA1.1, D.MI.PAD9.1, D.MI.PAD21.1
D.COL4: D.AN.PAD9.1, D.AN.PAD21.1, D.L.PAD10.1, D.L.PAD27.1, D.L.S10.1, D.ME.PAD8.1, D.ME.S1.1, D.ME.S2.1, D.ME.S3.1, D.ME.S4.1, D.ME.S5.1, D.MI.PAD10.1, D.MI.PAD22.1
D.COL5: D.AN.PAD10.1, D.AN.PAD22.1, D.IN.PAD8.1, D.IN.S1.1, D.IN.S2.1, D.IN.S3.1, D.IN.S4.1, D.IN.S5.1, D.L.PAD11.1, D.L.PAD28.1, D.L.S11.1, D.ME.PAD9.1, D.ME.PAD21.1, D.MI.PAD11.1, D.MI.PAD23.1
D.COL6: D.AN.PAD11.1, D.AN.PAD23.1, D.IN.PAD9.1, D.IN.S6.1, D.IN.S7.1, D.IN.S8.1, D.IN.S9.1, D.IN.S10.1, D.L.PAD12.1, D.L.PAD29.1, D.L.S12.1, D.ME.PAD10.1, D.ME.PAD22.1, D.MI.PAD12.1, D.MI.PAD24.1
D.DAT0: D.L.L1.2, D.L.PAD16.1
D.DAT1: D.L.L12.4, D.L.PAD13.1, D.MI.L1.2, D.MI.PAD13.1
D.DAT2: D.AN.L1.2, D.AN.PAD13.1, D.MI.L5.4, D.MI.PAD25.1
D.DAT3: D.AN.L5.4, D.AN.PAD25.1, D.ME.L1.2, D.ME.PAD13.1
D.DAT4: D.IN.L1.2, D.IN.PAD13.1, D.ME.L5.4, D.ME.PAD25.1
D.GND: D.AN.C1.2, D.AN.L1.1, D.AN.L2.1, D.AN.L3.1, D.AN.L4.1, D.AN.L5.1, D.AN.PAD7.1, D.AN.PAD20.1, D.IN.C1.2, D.IN.L1.1, D.IN.L2.1, D.IN.L3.1, D.IN.L4.1, D.IN.L5.1, D.IN.L6.1, D.IN.L7.1, D.IN.L8.1, D.IN.L9.1, D.IN.L10.1, D.IN.PAD7.1, D.L.C1.2, D.L.L1.1, D.L.L2.1, D.L.L3.1, D.L.L4.1, D.L.L5.1, D.L.L6.1, D.L.L7.1, D.L.L8.1, D.L.L9.1, D.L.L10.1, D.L.L11.1, D.L.L12.1, D.L.PAD7.1, D.L.PAD14.1, D.L.PAD30.1, D.ME.C1.2, D.ME.L1.1, D.ME.L2.1, D.ME.L3.1, D.ME.L4.1, D.ME.L5.1, D.ME.PAD7.1, D.ME.PAD20.1, D.MI.C1.2, D.MI.L1.1, D.MI.L2.1, D.MI.L3.1, D.MI.L4.1, D.MI.L5.1, D.MI.PAD7.1, D.MI.PAD20.1
D.IN.c1_r0: D.IN.D5.2, D.IN.S5.2
D.IN.c1_r1: D.IN.D4.2, D.IN.S4.2
D.IN.c1_r2: D.IN.D3.2, D.IN.S3.2
D.IN.c1_r3: D.IN.D2.2, D.IN.S2.2
D.IN.c1_r4: D.IN.D1.2, D.IN.S1.2
D.IN.c2_r0: D.IN.D10.2, D.IN.S10.2
D.IN.c2_r1: D.IN.D9.2, D.IN.S9.2
D.IN.c2_r2: D.IN.D8.2, D.IN.S8.2
D.IN.c2_r3: D.IN.D7.2, D.IN.S7.2
D.IN.c2_r4: D.IN.D6.2, D.IN.S6.2
D.IN.rgb1: D.IN.L1.4, D.IN.L2.2
D.IN.rgb2: D.IN.L2.4, D.IN.L3.2
D.IN.rgb3: D.IN.L3.4, D.IN.L4.2
D.IN.rgb4: D.IN.L4.4, D.IN.L5.2
D.IN.rgb5: D.IN.L5.4, D.IN.L6.2
D.IN.rgb6: D.IN.L6.4, D.IN.L7.2
D.IN.rgb7: D.IN.L7.4, D.IN.L8.2
D.IN.rgb8: D.IN.L8.4, D.IN.L9.2
D.IN.rgb9: D.IN.L9.4, D.IN.L10.2
D.L.arw_down: D.L.DA3.2, D.L.SA3.2
D.L.arw_left: D.L.DA1.2, D.L.SA1.2
D.L.arw_right: D.L.DA4.2, D.L.SA4.2
D.L.arw_up: D.L.DA2.2, D.L.SA2.2
D.L.c0_r0: D.L.D5.2, D.L.S5.2
D.L.c0_r1: D.L.D4.2, D.L.S4.2
D.L.c0_r2: D.L.D3.2, D.L.S3.2
D.L.c0_r3: D.L.D2.2, D.L.S2.2
D.L.c0_r4: D.L.D1.2, D.L.S1.2
D.L.c1_r0: D.L.D9.2, D.L.S9.2
D.L.c1_r1: D.L.D8.2, D.L.S8.2
D.L.c1_r2: D.L.D7.2, D.L.S7.2
D.L.c1_r3: D.L.D6.2, D.L.S6.2
D.L.cmd_r5: D.L.D10.2, D.L.S10.2
D.L.ret_r5: D.L.D11.2, D.L.S11.2
D.L.rgb1: D.L.L1.4, D.L.L2.2
D.L.rgb2: D.L.L2.4, D.L.L3.2
D.L.rgb3: D.L.L3.4, D.L.L4.2
D.L.rgb4: D.L.L4.4, D.L.L5.2
D.L.rgb5: D.L.L5.4, D.L.L6.2
D.L.rgb6: D.L.L6.4, D.L.L7.2
D.L.rgb7: D.L.L7.4, D.L.L8.2
D.L.rgb8: D.L.L8.4, D.L.L9.2
D.L.rgb9: D.L.L9.4, D.L.L10.2
D.L.rgb10: D.L.L10.4, D.L.L11.2
D.L.rgb11: D.L.L11.4, D.L.L12.2
D.L.spc_r5: D.L.D12.2, D.L.S12.2
D.ME.c1_r0: D.ME.D5.2, D.ME.S5.2
D.ME.c1_r1: D.ME.D4.2, D.ME.S4.2
D.ME.c1_r2: D.ME.D3.2, D.ME.S3.2
D.ME.c1_r3: D.ME.D2.2, D.ME.S2.2
D.ME.c1_r4: D.ME.D1.2, D.ME.S1.2
D.ME.livre.C4: D.ME.PAD11.1, D.ME.PAD23.1
D.ME.livre.C5: D.ME.PAD12.1, D.ME.PAD24.1
D.ME.rgb1: D.ME.L1.4, D.ME.L2.2
D.ME.rgb2: D.ME.L2.4, D.ME.L3.2
D.ME.rgb3: D.ME.L3.4, D.ME.L4.2
D.ME.rgb4: D.ME.L4.4, D.ME.L5.2
D.MI.c1_r0: D.MI.D5.2, D.MI.S5.2
D.MI.c1_r1: D.MI.D4.2, D.MI.S4.2
D.MI.c1_r2: D.MI.D3.2, D.MI.S3.2
D.MI.c1_r3: D.MI.D2.2, D.MI.S2.2
D.MI.c1_r4: D.MI.D1.2, D.MI.S1.2
D.MI.rgb1: D.MI.L1.4, D.MI.L2.2
D.MI.rgb2: D.MI.L2.4, D.MI.L3.2
D.MI.rgb3: D.MI.L3.4, D.MI.L4.2
D.MI.rgb4: D.MI.L4.4, D.MI.L5.2
D.R0: D.AN.D5.1, D.AN.PAD1.1, D.AN.PAD14.1, D.IN.D5.1, D.IN.D10.1, D.IN.PAD1.1, D.L.D5.1, D.L.D9.1, D.L.PAD1.1, D.L.PAD17.1, D.ME.D5.1, D.ME.PAD1.1, D.ME.PAD14.1, D.MI.D5.1, D.MI.PAD1.1, D.MI.PAD14.1
D.R1: D.AN.D4.1, D.AN.PAD2.1, D.AN.PAD15.1, D.IN.D4.1, D.IN.D9.1, D.IN.PAD2.1, D.L.D4.1, D.L.D8.1, D.L.PAD2.1, D.L.PAD18.1, D.ME.D4.1, D.ME.PAD2.1, D.ME.PAD15.1, D.MI.D4.1, D.MI.PAD2.1, D.MI.PAD15.1
D.R2: D.AN.D3.1, D.AN.PAD3.1, D.AN.PAD16.1, D.IN.D3.1, D.IN.D8.1, D.IN.PAD3.1, D.L.D3.1, D.L.D7.1, D.L.PAD3.1, D.L.PAD19.1, D.ME.D3.1, D.ME.PAD3.1, D.ME.PAD16.1, D.MI.D3.1, D.MI.PAD3.1, D.MI.PAD16.1
D.R3: D.AN.D2.1, D.AN.PAD4.1, D.AN.PAD17.1, D.IN.D2.1, D.IN.D7.1, D.IN.PAD4.1, D.L.D2.1, D.L.D6.1, D.L.PAD4.1, D.L.PAD20.1, D.ME.D2.1, D.ME.PAD4.1, D.ME.PAD17.1, D.MI.D2.1, D.MI.PAD4.1, D.MI.PAD17.1
D.R4: D.AN.D1.1, D.AN.PAD5.1, D.AN.PAD18.1, D.IN.D1.1, D.IN.D6.1, D.IN.PAD5.1, D.L.D1.1, D.L.PAD5.1, D.L.PAD21.1, D.ME.D1.1, D.ME.PAD5.1, D.ME.PAD18.1, D.MI.D1.1, D.MI.PAD5.1, D.MI.PAD18.1
D.R5: D.L.D10.1, D.L.D11.1, D.L.D12.1, D.L.DA1.1, D.L.DA2.1, D.L.DA3.1, D.L.DA4.1, D.L.PAD22.1
D.VLED: D.AN.C1.1, D.AN.L1.3, D.AN.L2.3, D.AN.L3.3, D.AN.L4.3, D.AN.L5.3, D.AN.PAD6.1, D.AN.PAD19.1, D.IN.C1.1, D.IN.L1.3, D.IN.L2.3, D.IN.L3.3, D.IN.L4.3, D.IN.L5.3, D.IN.L6.3, D.IN.L7.3, D.IN.L8.3, D.IN.L9.3, D.IN.L10.3, D.IN.PAD6.1, D.L.C1.1, D.L.L1.3, D.L.L2.3, D.L.L3.3, D.L.L4.3, D.L.L5.3, D.L.L6.3, D.L.L7.3, D.L.L8.3, D.L.L9.3, D.L.L10.3, D.L.L11.3, D.L.L12.3, D.L.PAD6.1, D.L.PAD15.1, D.ME.C1.1, D.ME.L1.3, D.ME.L2.3, D.ME.L3.3, D.ME.L4.3, D.ME.L5.3, D.ME.PAD6.1, D.ME.PAD19.1, D.MI.C1.1, D.MI.L1.3, D.MI.L2.3, D.MI.L3.3, D.MI.L4.3, D.MI.L5.3, D.MI.PAD6.1, D.MI.PAD19.1
E.AN.c1_r0: E.AN.D5.2, E.AN.S5.2
E.AN.c1_r1: E.AN.D4.2, E.AN.S4.2
E.AN.c1_r2: E.AN.D3.2, E.AN.S3.2
E.AN.c1_r3: E.AN.D2.2, E.AN.S2.2
E.AN.c1_r4: E.AN.D1.2, E.AN.S1.2
E.AN.livre.C5: E.AN.PAD12.1, E.AN.PAD24.1
E.AN.rgb1: E.AN.L1.4, E.AN.L2.2
E.AN.rgb2: E.AN.L2.4, E.AN.L3.2
E.AN.rgb3: E.AN.L3.4, E.AN.L4.2
E.AN.rgb4: E.AN.L4.4, E.AN.L5.2
E.COL0: E.L.PAD23.1, E.L.S1.1, E.L.S2.1, E.L.S3.1, E.L.S4.1, E.L.S5.1, E.L.S8.1
E.COL1: E.L.PAD24.1, E.L.S6.1, E.L.S7.1, E.L.S9.1
E.COL2: E.L.PAD8.1, E.L.PAD25.1, E.L.S10.1, E.MI.PAD8.1, E.MI.S1.1, E.MI.S2.1, E.MI.S3.1, E.MI.S4.1, E.MI.S5.1
E.COL3: E.AN.PAD8.1, E.AN.S1.1, E.AN.S2.1, E.AN.S3.1, E.AN.S4.1, E.AN.S5.1, E.L.PAD9.1, E.L.PAD26.1, E.L.S11.1, E.MI.PAD9.1, E.MI.PAD21.1
E.COL4: E.AN.PAD9.1, E.AN.PAD21.1, E.L.PAD10.1, E.L.PAD27.1, E.L.S12.1, E.ME.PAD8.1, E.ME.S1.1, E.ME.S2.1, E.ME.S3.1, E.ME.S4.1, E.ME.S5.1, E.MI.PAD10.1, E.MI.PAD22.1
E.COL5: E.AN.PAD10.1, E.AN.PAD22.1, E.IN.PAD8.1, E.IN.S1.1, E.IN.S2.1, E.IN.S3.1, E.IN.S4.1, E.IN.S5.1, E.L.PAD11.1, E.L.PAD28.1, E.L.S13.1, E.ME.PAD9.1, E.ME.PAD21.1, E.MI.PAD11.1, E.MI.PAD23.1
E.COL6: E.AN.PAD11.1, E.AN.PAD23.1, E.IN.PAD9.1, E.IN.S6.1, E.IN.S7.1, E.IN.S8.1, E.IN.S9.1, E.IN.S10.1, E.L.PAD12.1, E.L.PAD29.1, E.ME.PAD10.1, E.ME.PAD22.1, E.MI.PAD12.1, E.MI.PAD24.1
E.DAT0: E.L.L1.2, E.L.PAD16.1
E.DAT1: E.L.L13.4, E.L.PAD13.1, E.MI.L1.2, E.MI.PAD13.1
E.DAT2: E.AN.L1.2, E.AN.PAD13.1, E.MI.L5.4, E.MI.PAD25.1
E.DAT3: E.AN.L5.4, E.AN.PAD25.1, E.ME.L1.2, E.ME.PAD13.1
E.DAT4: E.IN.L1.2, E.IN.PAD13.1, E.ME.L5.4, E.ME.PAD25.1
E.GND: E.AN.C1.2, E.AN.L1.1, E.AN.L2.1, E.AN.L3.1, E.AN.L4.1, E.AN.L5.1, E.AN.PAD7.1, E.AN.PAD20.1, E.IN.C1.2, E.IN.L1.1, E.IN.L2.1, E.IN.L3.1, E.IN.L4.1, E.IN.L5.1, E.IN.L6.1, E.IN.L7.1, E.IN.L8.1, E.IN.L9.1, E.IN.L10.1, E.IN.PAD7.1, E.L.C1.2, E.L.L1.1, E.L.L2.1, E.L.L3.1, E.L.L4.1, E.L.L5.1, E.L.L6.1, E.L.L7.1, E.L.L8.1, E.L.L9.1, E.L.L10.1, E.L.L11.1, E.L.L12.1, E.L.L13.1, E.L.LED1.1, E.L.LED2.1, E.L.LED3.1, E.L.PAD7.1, E.L.PAD14.1, E.L.PAD33.1, E.ME.C1.2, E.ME.L1.1, E.ME.L2.1, E.ME.L3.1, E.ME.L4.1, E.ME.L5.1, E.ME.PAD7.1, E.ME.PAD20.1, E.MI.C1.2, E.MI.L1.1, E.MI.L2.1, E.MI.L3.1, E.MI.L4.1, E.MI.L5.1, E.MI.PAD7.1, E.MI.PAD20.1
E.IN.c1_r0: E.IN.D5.2, E.IN.S5.2
E.IN.c1_r1: E.IN.D4.2, E.IN.S4.2
E.IN.c1_r2: E.IN.D3.2, E.IN.S3.2
E.IN.c1_r3: E.IN.D2.2, E.IN.S2.2
E.IN.c1_r4: E.IN.D1.2, E.IN.S1.2
E.IN.c2_r0: E.IN.D10.2, E.IN.S10.2
E.IN.c2_r1: E.IN.D9.2, E.IN.S9.2
E.IN.c2_r2: E.IN.D8.2, E.IN.S8.2
E.IN.c2_r3: E.IN.D7.2, E.IN.S7.2
E.IN.c2_r4: E.IN.D6.2, E.IN.S6.2
E.IN.rgb1: E.IN.L1.4, E.IN.L2.2
E.IN.rgb2: E.IN.L2.4, E.IN.L3.2
E.IN.rgb3: E.IN.L3.4, E.IN.L4.2
E.IN.rgb4: E.IN.L4.4, E.IN.L5.2
E.IN.rgb5: E.IN.L5.4, E.IN.L6.2
E.IN.rgb6: E.IN.L6.4, E.IN.L7.2
E.IN.rgb7: E.IN.L7.4, E.IN.L8.2
E.IN.rgb8: E.IN.L8.4, E.IN.L9.2
E.IN.rgb9: E.IN.L9.4, E.IN.L10.2
E.L.c0_r0: E.L.D5.2, E.L.S5.2
E.L.c0_r1: E.L.D4.2, E.L.S4.2
E.L.c0_r2: E.L.D3.2, E.L.S3.2
E.L.c0_r3: E.L.D2.2, E.L.S2.2
E.L.c0_r4: E.L.D1.2, E.L.S1.2
E.L.c1_r0: E.L.D7.2, E.L.S7.2
E.L.c1_r1: E.L.D6.2, E.L.S6.2
E.L.cmd_r5: E.L.D11.2, E.L.S11.2
E.L.ctl_r5: E.L.D9.2, E.L.S9.2
E.L.del_r5: E.L.D12.2, E.L.S12.2
E.L.fn_r5: E.L.D8.2, E.L.S8.2
E.L.led1_a: E.L.LED1.2, E.L.R1.2
E.L.led2_a: E.L.LED2.2, E.L.R2.2
E.L.led3_a: E.L.LED3.2, E.L.R3.2
E.L.opt_r5: E.L.D10.2, E.L.S10.2
E.L.rgb1: E.L.L1.4, E.L.L2.2
E.L.rgb2: E.L.L2.4, E.L.L3.2
E.L.rgb3: E.L.L3.4, E.L.L4.2
E.L.rgb4: E.L.L4.4, E.L.L5.2
E.L.rgb5: E.L.L5.4, E.L.L6.2
E.L.rgb6: E.L.L6.4, E.L.L7.2
E.L.rgb7: E.L.L7.4, E.L.L8.2
E.L.rgb8: E.L.L8.4, E.L.L9.2
E.L.rgb9: E.L.L9.4, E.L.L10.2
E.L.rgb10: E.L.L10.4, E.L.L11.2
E.L.rgb11: E.L.L11.4, E.L.L12.2
E.L.rgb12: E.L.L12.4, E.L.L13.2
E.L.spc_r5: E.L.D13.2, E.L.S13.2
E.LED1: E.L.PAD30.1, E.L.R1.1
E.LED2: E.L.PAD31.1, E.L.R2.1
E.LED3: E.L.PAD32.1, E.L.R3.1
E.ME.c1_r0: E.ME.D5.2, E.ME.S5.2
E.ME.c1_r1: E.ME.D4.2, E.ME.S4.2
E.ME.c1_r2: E.ME.D3.2, E.ME.S3.2
E.ME.c1_r3: E.ME.D2.2, E.ME.S2.2
E.ME.c1_r4: E.ME.D1.2, E.ME.S1.2
E.ME.livre.C4: E.ME.PAD11.1, E.ME.PAD23.1
E.ME.livre.C5: E.ME.PAD12.1, E.ME.PAD24.1
E.ME.rgb1: E.ME.L1.4, E.ME.L2.2
E.ME.rgb2: E.ME.L2.4, E.ME.L3.2
E.ME.rgb3: E.ME.L3.4, E.ME.L4.2
E.ME.rgb4: E.ME.L4.4, E.ME.L5.2
E.MI.c1_r0: E.MI.D5.2, E.MI.S5.2
E.MI.c1_r1: E.MI.D4.2, E.MI.S4.2
E.MI.c1_r2: E.MI.D3.2, E.MI.S3.2
E.MI.c1_r3: E.MI.D2.2, E.MI.S2.2
E.MI.c1_r4: E.MI.D1.2, E.MI.S1.2
E.MI.rgb1: E.MI.L1.4, E.MI.L2.2
E.MI.rgb2: E.MI.L2.4, E.MI.L3.2
E.MI.rgb3: E.MI.L3.4, E.MI.L4.2
E.MI.rgb4: E.MI.L4.4, E.MI.L5.2
E.R0: E.AN.D5.1, E.AN.PAD1.1, E.AN.PAD14.1, E.IN.D5.1, E.IN.D10.1, E.IN.PAD1.1, E.L.D5.1, E.L.D7.1, E.L.PAD1.1, E.L.PAD17.1, E.ME.D5.1, E.ME.PAD1.1, E.ME.PAD14.1, E.MI.D5.1, E.MI.PAD1.1, E.MI.PAD14.1
E.R1: E.AN.D4.1, E.AN.PAD2.1, E.AN.PAD15.1, E.IN.D4.1, E.IN.D9.1, E.IN.PAD2.1, E.L.D4.1, E.L.D6.1, E.L.PAD2.1, E.L.PAD18.1, E.ME.D4.1, E.ME.PAD2.1, E.ME.PAD15.1, E.MI.D4.1, E.MI.PAD2.1, E.MI.PAD15.1
E.R2: E.AN.D3.1, E.AN.PAD3.1, E.AN.PAD16.1, E.IN.D3.1, E.IN.D8.1, E.IN.PAD3.1, E.L.D3.1, E.L.PAD3.1, E.L.PAD19.1, E.ME.D3.1, E.ME.PAD3.1, E.ME.PAD16.1, E.MI.D3.1, E.MI.PAD3.1, E.MI.PAD16.1
E.R3: E.AN.D2.1, E.AN.PAD4.1, E.AN.PAD17.1, E.IN.D2.1, E.IN.D7.1, E.IN.PAD4.1, E.L.D2.1, E.L.PAD4.1, E.L.PAD20.1, E.ME.D2.1, E.ME.PAD4.1, E.ME.PAD17.1, E.MI.D2.1, E.MI.PAD4.1, E.MI.PAD17.1
E.R4: E.AN.D1.1, E.AN.PAD5.1, E.AN.PAD18.1, E.IN.D1.1, E.IN.D6.1, E.IN.PAD5.1, E.L.D1.1, E.L.PAD5.1, E.L.PAD21.1, E.ME.D1.1, E.ME.PAD5.1, E.ME.PAD18.1, E.MI.D1.1, E.MI.PAD5.1, E.MI.PAD18.1
E.R5: E.L.D8.1, E.L.D9.1, E.L.D10.1, E.L.D11.1, E.L.D12.1, E.L.D13.1, E.L.PAD22.1
E.VLED: E.AN.C1.1, E.AN.L1.3, E.AN.L2.3, E.AN.L3.3, E.AN.L4.3, E.AN.L5.3, E.AN.PAD6.1, E.AN.PAD19.1, E.IN.C1.1, E.IN.L1.3, E.IN.L2.3, E.IN.L3.3, E.IN.L4.3, E.IN.L5.3, E.IN.L6.3, E.IN.L7.3, E.IN.L8.3, E.IN.L9.3, E.IN.L10.3, E.IN.PAD6.1, E.L.C1.1, E.L.L1.3, E.L.L2.3, E.L.L3.3, E.L.L4.3, E.L.L5.3, E.L.L6.3, E.L.L7.3, E.L.L8.3, E.L.L9.3, E.L.L10.3, E.L.L11.3, E.L.L12.3, E.L.L13.3, E.L.PAD6.1, E.L.PAD15.1, E.ME.C1.1, E.ME.L1.3, E.ME.L2.3, E.ME.L3.3, E.ME.L4.3, E.ME.L5.3, E.ME.PAD6.1, E.ME.PAD19.1, E.MI.C1.1, E.MI.L1.3, E.MI.L2.3, E.MI.L3.3, E.MI.L4.3, E.MI.L5.3, E.MI.PAD6.1, E.MI.PAD19.1

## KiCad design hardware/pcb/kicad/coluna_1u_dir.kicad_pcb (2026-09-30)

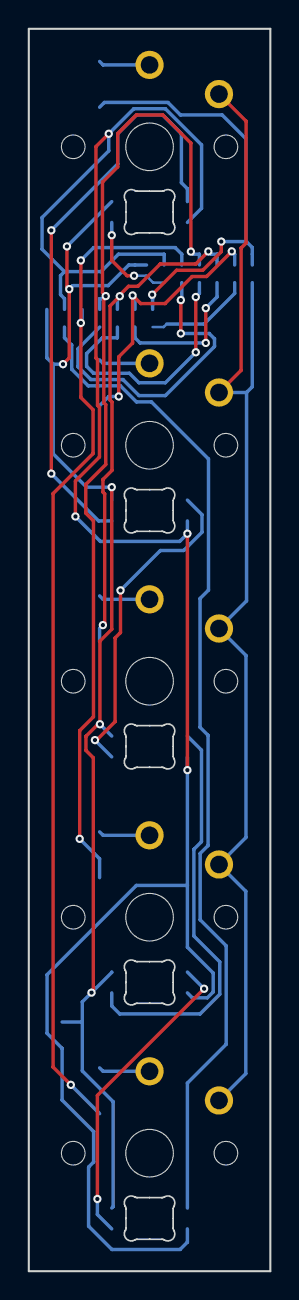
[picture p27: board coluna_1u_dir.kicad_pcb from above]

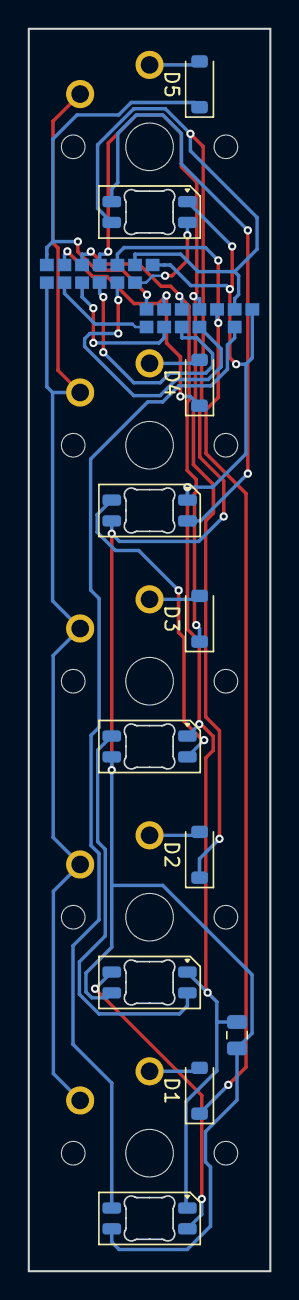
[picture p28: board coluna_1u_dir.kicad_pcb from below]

Board: 2 copper layers, 17.4 x 89.5 mm, 41 parts (11 on the bottom side), 23 nets.

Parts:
C1: 4.7uF; C_0805_2012Metric
D1, D2, D3, D4, D5: 1N4148W; D_SOD-123
L1, L2, L3, L4, L5: SK6812MINI-E; LED_SK6812MINI-E_3.2x2.8mm_P1.5mm_ReverseMount
PAD1, PAD2, PAD3, PAD4, PAD5, PAD6, PAD7, PAD8, PAD9, PAD10, PAD11, PAD12, PAD13, PAD14, PAD15, PAD16, PAD17, PAD18, PAD19, PAD20, PAD21, PAD22, PAD23, PAD24, PAD25: SMDPad
S1, S2, S3, S4, S5: PG1350

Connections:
C1: PAD8.1, S1.1, S2.1, S3.1, S4.1, S5.1
C2: PAD9.1, PAD21.1
C3: PAD10.1, PAD22.1
C4: PAD11.1, PAD23.1
C5: PAD12.1, PAD24.1
DIN: L1.2, PAD13.1
DOUT: L5.4, PAD25.1
GND: C1.2, L1.1, L2.1, L3.1, L4.1, L5.1, PAD7.1, PAD20.1
R0: D5.1, PAD1.1, PAD14.1
R1: D4.1, PAD2.1, PAD15.1
R2: D3.1, PAD3.1, PAD16.1
R3: D2.1, PAD4.1, PAD17.1
R4: D1.1, PAD5.1, PAD18.1
VLED: C1.1, L1.3, L2.3, L3.3, L4.3, L5.3, PAD6.1, PAD19.1
c1_r0: D5.2, S5.2
c1_r1: D4.2, S4.2
c1_r2: D3.2, S3.2
c1_r3: D2.2, S2.2
c1_r4: D1.2, S1.2
rgb1: L1.4, L2.2
rgb2: L2.4, L3.2
rgb3: L3.4, L4.2
rgb4: L4.4, L5.2

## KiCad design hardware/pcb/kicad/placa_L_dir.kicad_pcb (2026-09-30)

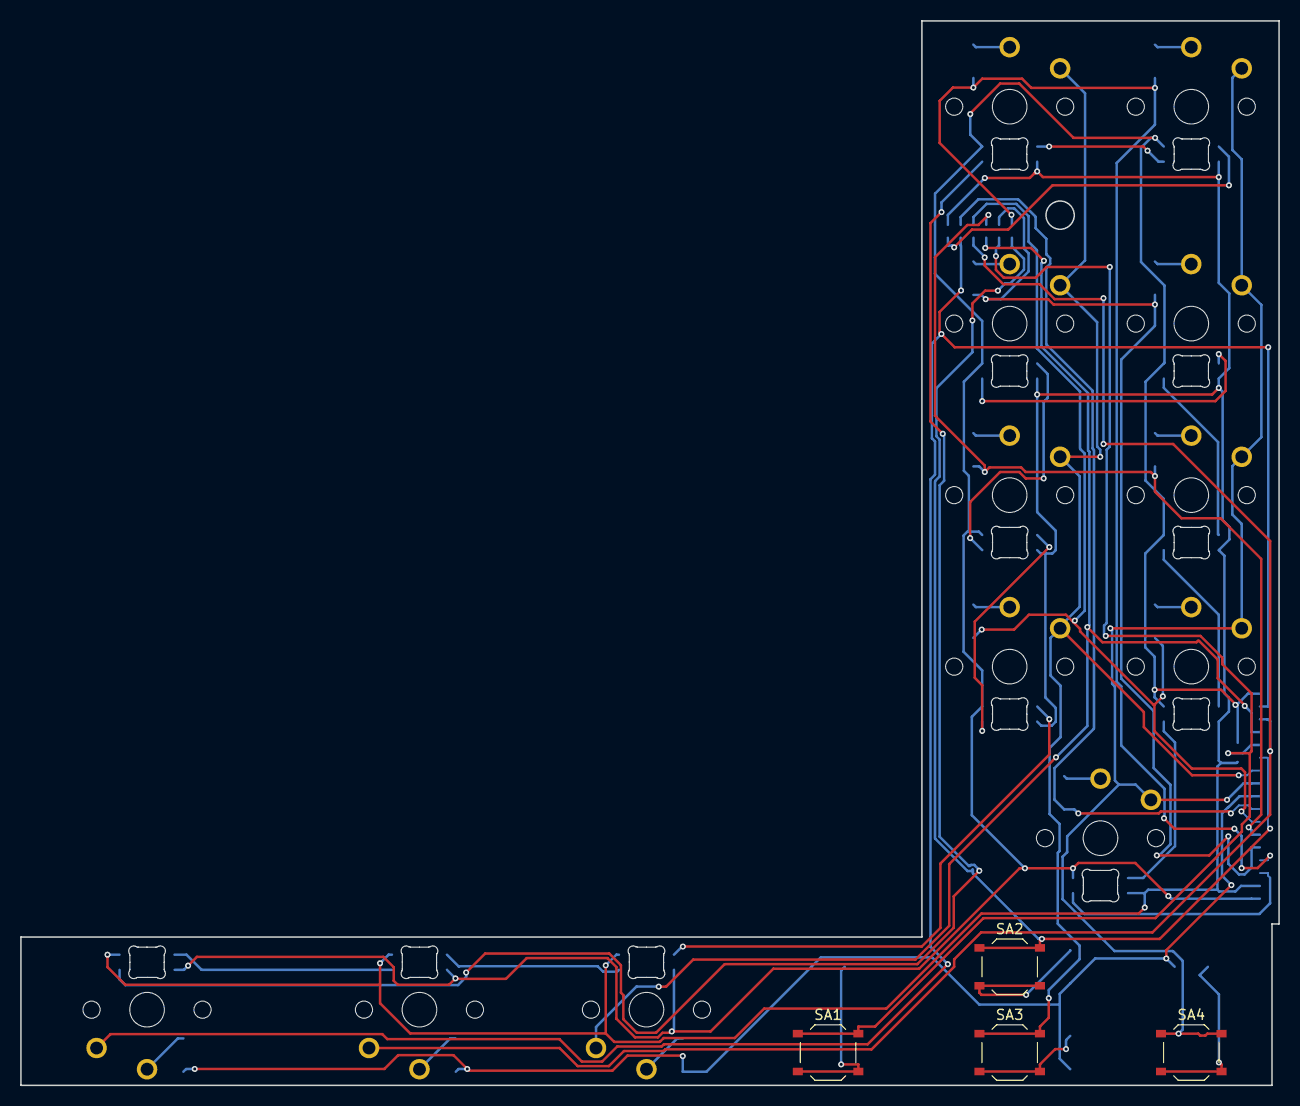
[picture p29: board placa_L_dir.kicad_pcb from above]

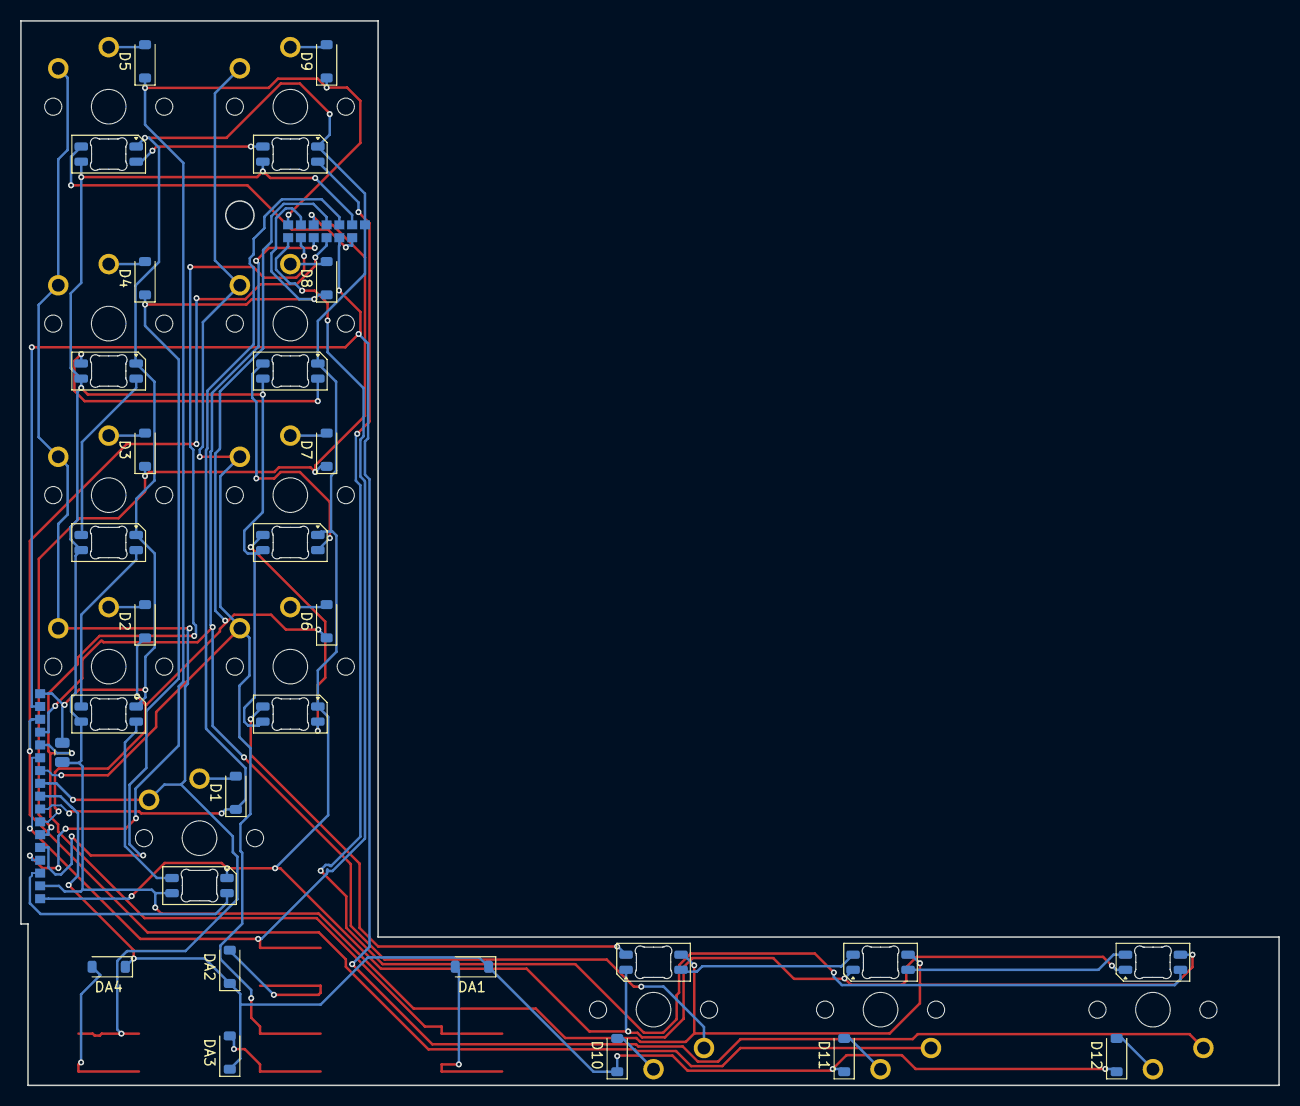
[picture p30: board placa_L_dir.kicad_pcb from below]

Board: 2 copper layers, 124.7 x 105.5 mm, 75 parts (29 on the bottom side), 44 nets.

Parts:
C1: 4.7uF; C_0805_2012Metric
D1, D2, D3, D4, D5, D6, D7, D8, D9, D10, D11, D12: 1N4148W; D_SOD-123
DA1, DA2, DA3, DA4: 1N4148W; D_SOD-123
L1, L2, L3, L4, L5, L6, L7, L8, L9, L10, L11, L12: SK6812MINI-E; LED_SK6812MINI-E_3.2x2.8mm_P1.5mm_ReverseMount
PAD1, PAD2, PAD3, PAD4, PAD5, PAD6, PAD7, PAD8, PAD9, PAD10, PAD11, PAD12, PAD13, PAD14, PAD15, PAD16, PAD17, PAD18, PAD19, PAD20, PAD21, PAD22, PAD23, PAD24, PAD25, PAD26, PAD27, PAD28, PAD29, PAD30: SMDPad
S1, S2, S3, S4, S5, S6, S7, S8, S9, S10, S11, S12: PG1350
SA1, SA2, SA3, SA4: TS-1187A; SW_Push_1P1T_XKB_TS-1187A

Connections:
COL0: PAD23.1, S1.1, S2.1, S3.1, S4.1, S5.1, SA4.1
COL1: PAD24.1, S6.1, S7.1, S8.1, S9.1, SA3.1
COL2: PAD8.1, PAD25.1, SA2.1
COL3: PAD9.1, PAD26.1, SA1.1
COL4: PAD10.1, PAD27.1, S10.1
COL5: PAD11.1, PAD28.1, S11.1
COL6: PAD12.1, PAD29.1, S12.1
DIN: L1.2, PAD16.1
DOUT: L12.4, PAD13.1
GND: C1.2, L1.1, L2.1, L3.1, L4.1, L5.1, L6.1, L7.1, L8.1, L9.1, L10.1, L11.1, L12.1, PAD7.1, PAD14.1, PAD30.1
R0: D5.1, D9.1, PAD1.1, PAD17.1
R1: D4.1, D8.1, PAD2.1, PAD18.1
R2: D3.1, D7.1, PAD3.1, PAD19.1
R3: D2.1, D6.1, PAD4.1, PAD20.1
R4: D1.1, PAD5.1, PAD21.1
R5: D10.1, D11.1, D12.1, DA1.1, DA2.1, DA3.1, DA4.1, PAD22.1
VLED: C1.1, L1.3, L2.3, L3.3, L4.3, L5.3, L6.3, L7.3, L8.3, L9.3, L10.3, L11.3, L12.3, PAD6.1, PAD15.1
arw_down: DA3.2, SA3.2
arw_left: DA1.2, SA1.2
arw_right: DA4.2, SA4.2
arw_up: DA2.2, SA2.2
c0_r0: D5.2, S5.2
c0_r1: D4.2, S4.2
c0_r2: D3.2, S3.2
c0_r3: D2.2, S2.2
c0_r4: D1.2, S1.2
c1_r0: D9.2, S9.2
c1_r1: D8.2, S8.2
c1_r2: D7.2, S7.2
c1_r3: D6.2, S6.2
cmd_r5: D10.2, S10.2
ret_r5: D11.2, S11.2
rgb1: L1.4, L2.2
rgb2: L2.4, L3.2
rgb3: L3.4, L4.2
rgb4: L4.4, L5.2
rgb5: L5.4, L6.2
rgb6: L6.4, L7.2
rgb7: L7.4, L8.2
rgb8: L8.4, L9.2
rgb9: L9.4, L10.2
rgb10: L10.4, L11.2
rgb11: L11.4, L12.2
spc_r5: D12.2, S12.2

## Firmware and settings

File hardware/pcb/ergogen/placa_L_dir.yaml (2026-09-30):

meta:
  engine: 4.1.0
  name: yggi_placa_L_dir
  author: Yggi Keyboard
  version: rev0
units:
  kx: 18
  ky: 17
points:
  zones:
    big:
      anchor:
        shift: [-kx/2, 0]
      key:
        width: 2*kx
        column_net: COL0
      columns:
        c0:
      rows:
        r4:
          row_net: R4
    fixed:
      anchor:
        shift: [0, ky]
      key:
        spread: -kx
        padding: ky
      columns:
        c0:
          key:
            column_net: COL0
        c1:
          key:
            column_net: COL1
      rows:
        r3:
          row_net: R3
        r2:
          row_net: R2
        r1:
          row_net: R1
          padding: ky + 4.5
        r0:
          row_net: R0
    bar:
      anchor:
        shift: [-54, -ky]
      key:
        padding: ky
        row_net: R5
      columns:
        cmd:
          key:
            column_net: COL4
        ret:
          key:
            spread: -22.5
            width: 1.5*kx
            column_net: COL5
        spc:
          key:
            spread: -27
            width: 1.5*kx
            column_net: COL6
      rows:
        r5:
outlines:
  board:
    - what: rectangle
      where: big_c0_r4
      adjust:
        shift: [0.0, 36.25]
      size: [35.4, 89.5]
    - what: rectangle
      where: big_c0_r4
      adjust:
        shift: [-45.0, -17.15]
      size: [124, 14.7]
    - what: rectangle
      where: big_c0_r4
      adjust:
        shift: [-0.34999999999999964, -9.1]
      size: [34.7, 1.6]
    - what: circle
      where: big_c0_r4
      adjust:
        shift: [-4.0, 61.75]
      radius: 1.4
      operation: subtract
  keys:
    - what: rectangle
      where: true
      size: [kx-0.5, ky-0.5]
pcbs:
  placa_L_dir:
    outlines:
      main:
        outline: board
    footprints:
      choc:
        what: choc
        where: -/_r5$/
        params:
          keycaps: true
          reverse: false
          hotswap: false
          from: "{{column_net}}"
          to: "{{colrow}}"
      diode:
        what: diode
        where: -/_r5$/
        params:
          from: "{{colrow}}"
          to: "{{row_net}}"
        adjust:
          shift: [0, -5.3]
      choc_bar:
        what: choc
        where: /_r5$/
        adjust:
          rotate: 180
        params:
          keycaps: true
          reverse: false
          hotswap: false
          from: "{{column_net}}"
          to: "{{colrow}}"
      diode_bar:
        what: diode
        where: /_r5$/
        params:
          from: "{{colrow}}"
          to: "{{row_net}}"
        adjust:
          shift: [0, 5.3]
      jout_0:
        what: pad
        where: big_c0_r4
        adjust:
          shift: [-8.78, 60.785]
        params:
          front: false
          back: true
          width: 1
          height: 0.9
          text: ''
          net: R0
      jout_1:
        what: pad
        where: big_c0_r4
        adjust:
          shift: [-10.05, 60.785]
        params:
          front: false
          back: true
          width: 1
          height: 0.9
          text: ''
          net: R1
      jout_2:
        what: pad
        where: big_c0_r4
        adjust:
          shift: [-11.32, 60.785]
        params:
          front: false
          back: true
          width: 1
          height: 0.9
          text: ''
          net: R2
      jout_3:
        what: pad
        where: big_c0_r4
        adjust:
          shift: [-12.59, 60.785]
        params:
          front: false
          back: true
          width: 1
          height: 0.9
          text: ''
          net: R3
      jout_4:
        what: pad
        where: big_c0_r4
        adjust:
          shift: [-13.86, 60.785]
        params:
          front: false
          back: true
          width: 1
          height: 0.9
          text: ''
          net: R4
      jout_5:
        what: pad
        where: big_c0_r4
        adjust:
          shift: [-15.13, 60.785]
        params:
          front: false
          back: true
          width: 1
          height: 0.9
          text: ''
          net: VLED
      jout_6:
        what: pad
        where: big_c0_r4
        adjust:
          shift: [-16.4, 60.785]
        params:
          front: false
          back: true
          width: 1
          height: 0.9
          text: ''
          net: GND
      jout_7:
        what: pad
        where: big_c0_r4
        adjust:
          shift: [-8.78, 59.515]
        params:
          front: false
          back: true
          width: 1
          height: 0.9
          text: ''
          net: COL2
      jout_8:
        what: pad
        where: big_c0_r4
        adjust:
          shift: [-10.05, 59.515]
        params:
          front: false
          back: true
          width: 1
          height: 0.9
          text: ''
          net: COL3
      jout_9:
        what: pad
        where: big_c0_r4
        adjust:
          shift: [-11.32, 59.515]
        params:
          front: false
          back: true
          width: 1
          height: 0.9
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

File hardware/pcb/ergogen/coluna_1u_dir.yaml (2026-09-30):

meta:
  engine: 4.1.0
  name: yggi_coluna_1u_dir
  author: Yggi Keyboard
  version: rev0
units:
  kx: 18
  ky: 17
points:
  zones:
    matrix:
      key:
        spread: kx
        padding: ky
      columns:
        c1:
          key:
            column_net: C1
      rows:
        r4:
          row_net: R4
        r3:
          row_net: R3
        r2:
          row_net: R2
        r1:
          row_net: R1
          padding: ky + 4.5
        r0:
          row_net: R0
outlines:
  board:
    - what: rectangle
      where: matrix_c1_r4
      adjust:
        shift: [0, 36.25]
      size: [17.4, 89.5]
  keys:
    - what: rectangle
      where: true
      size: [kx-0.5, ky-0.5]
pcbs:
  coluna_1u_dir:
    outlines:
      main:
        outline: board
    footprints:
      choc:
        what: choc
        where: true
        params:
          keycaps: true
          reverse: false
          hotswap: false
          from: "{{column_net}}"
          to: "{{colrow}}"
      diode:
        what: diode
        where: true
        params:
          from: "{{colrow}}"
          to: "{{row_net}}"
        adjust:
          shift: [0, -5.3]
      jin_0:
        what: pad
        where: matrix_c1_r4
        adjust:
          shift: [7.4, 63.985]
        params:
          front: false
          back: true
          width: 1
          height: 0.9
          text: ''
          net: R0
      jin_1:
        what: pad
        where: matrix_c1_r4
        adjust:
          shift: [6.13, 63.985]
        params:
          front: false
          back: true
          width: 1
          height: 0.9
          text: ''
          net: R1
      jin_2:
        what: pad
        where: matrix_c1_r4
        adjust:
          shift: [4.86, 63.985]
        params:
          front: false
          back: true
          width: 1
          height: 0.9
          text: ''
          net: R2
      jin_3:
        what: pad
        where: matrix_c1_r4
        adjust:
          shift: [3.59, 63.985]
        params:
          front: false
          back: true
          width: 1
          height: 0.9
          text: ''
          net: R3
      jin_4:
        what: pad
        where: matrix_c1_r4
        adjust:
          shift: [2.32, 63.985]
        params:
          front: false
          back: true
          width: 1
          height: 0.9
          text: ''
          net: R4
      jin_5:
        what: pad
        where: matrix_c1_r4
        adjust:
          shift: [1.05, 63.985]
        params:
          front: false
          back: true
          width: 1
          height: 0.9
          text: ''
          net: VLED
      jin_6:
        what: pad
        where: matrix_c1_r4
        adjust:
          shift: [-0.22, 63.985]
        params:
          front: false
          back: true
          width: 1
          height: 0.9
          text: ''
          net: GND
      jin_7:
        what: pad
        where: matrix_c1_r4
        adjust:
          shift: [7.4, 62.715]
        params:
          front: false
          back: true
          width: 1
          height: 0.9
          text: ''
          net: C1
      jin_8:
        what: pad
        where: matrix_c1_r4
        adjust:
          shift: [6.13, 62.715]
        params:
          front: false
          back: true
          width: 1
          height: 0.9
          text: ''
          net: C2
      jin_9:
        what: pad
        where: matrix_c1_r4
        adjust:
          shift: [4.86, 62.715]
        params:
          front: false
          back: true
          width: 1
          height: 0.9
          text: ''
          net: C3
      jin_10:
        what: pad
        where: matrix_c1_r4
        adjust:
          shift: [3.59, 62.715]
        params:
          front: false
          back: true
          width: 1
          height: 0.9
          text: ''
          net: C4
      jin_11:
        what: pad
        where: matrix_c1_r4
        adjust:
          shift: [2.32, 62.715]
        params:
          front: false
          back: true
          width: 1
          height: 0.9
          text: ''
          net: C5
      jin_12:
        what: pad
        where: matrix_c1_r4
        adjust:
          shift: [1.05, 62.715]
        params:
          front: false
          back: true
          width: 1
          height: 0.9
          text: ''
          net: DIN
      jout_0:
        what: pad
        where: matrix_c1_r4
        adjust:
          shift: [0.22, 60.785]
        params:
          front: false
          back: true
          width: 1
          height: 0.9
          text: ''
          net: R0
      jout_1:
        what: pad
        where: matrix_c1_r4
        adjust:
          shift: [-1.05, 60.785]
        params:
          front: false
          back: true
          width: 1
          height: 0.9
          text: ''
          net: R1
      jout_2:
        what: pad
        where: matrix_c1_r4
        adjust:
          shift: [-2.32, 60.785]
        params:
          front: false
          back: true
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

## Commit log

2026-09-30 Yggi Keyboard: mecanismo de stagger v3, layout, simulação e README
    - CAD paramétrico (OpenSCAD) do mecanismo v3: gavetas deslizantes sobre chassi
    imutável, placa-came com mola de força constante e trava, cunha traseira com
    bateria e MCU (5°), baia para e-reader, bordas externas arredondadas e faces
    de encaixe com ímãs e pogo. Versões v1 e v2 mantidas como histórico.
    - Verificação de colisões embutida (part="check") em 0/50/100/150%.
    - Layout B (7+7, Mac) com tecla Yggi e 3 LEDs, exportado para o KLE.
    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
    [yggi_stagger.scad, yggi_v2.scad, yggi_v3.scad]
2026-09-30 Simulação: LEDs no lugar certo e vista de frente com altura exagerada
2026-09-30 Simulação: raio-x de cima com conexões e nova simulação da mola em corte lateral
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2026-09-30 Circuitos: chassi como placa-mãe, uma placa por coluna móvel com cabo flat em laço
    - Raio-x de cima com camadas de placa-mãe, placas das colunas, cabos flat,
    MCU/carregador/USB-C, ímãs e pogo.
    - Novo diagrama de como os circuitos se ligam.
    - Cortes lateral e da mola mostram a placa-mãe e o laço do cabo flat rolando.
    - README atualizado com a arquitetura de 7 placas por metade.
2026-09-30 Diagrama de circuitos: legenda embaixo em vez de rótulos sobre as setas
2026-09-30 CAD v3: placa-mãe, placas por coluna e cabos flat em laço
    - Chassi vira placa-mãe: conectores dos cabos flat, conector placa-a-placa do
    bloco fixo e da barra no lado de cima; MCU nRF52840, carregador, conector da
    bateria e USB-C no lado de baixo, na faixa fixa da borda.
    - Cada coluna ganha conector próprio, janela no trenó e o laço do cabo flat
    (visual) que rola com o stagger.
    - Bandeja e cunha com bolsos para os componentes, saída do USB-C e canal dos
    fios da bateria. 4 novas verificações de colisão (64 no total, todas livres).
    - Simulação e README alinhados com as posições do CAD.
    [yggi_v3.scad]
2026-09-30 Placas em cadeia: placa L + 3 colunas 1u idênticas + coluna 2u (rev0)
    - hardware/pcb: placas geradas com Ergogen (KiCad + contornos DXF + prévia SVG).
    Barramento rotativo de 10 vias (R0–R4, C1–C5) deixa as 3 placas de 1u
    idênticas. Switches Choc com furos passantes (o soquete hot-swap Kailh não
    cabe na coluna de 17,4 mm). Placa L com cabeçalho de 18 pads para MCU externo
    na rev0 e furo do botão da trava. Nenhum pad sobreposto nem fora da borda.
    - CAD v3: placa-mãe substituída pela cadeia. Placa L (bloco fixo + barra) com
    MCU, carregador e conector da bateria embaixo e USB-C na frente da barra;
    pads e rasgos nas paredes para os jumpers na faixa entre F e números; pogo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
    [coluna_1u.dxf, coluna_1u.kicad_pcb, coluna_2u.dxf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]
2026-09-30 Reorganiza o repositório: hardware em hardware/, docs do produto na raiz
    - layout/, tools/ e a simulação (docs/simulacao.html + media) foram para hardware/.
    - O README detalhado virou hardware/README.md; a raiz ganhou um README curto.
    - docs/funcionalidades.md: rascunho das funcionalidades para discutir o software.
    - Caminhos e comandos atualizados nos READMEs e nas ferramentas.
2026-09-30 Placas rev0 roteadas: route.py (Freerouting + DRC), LEDs na placa L, diodos SOD-123
    - route.py termina as placas do Ergogen no KiCad 10: regras da JLCPCB,
    diodo SOD-123 na face de baixo, 3 LEDs 0805 + resistores na placa L,
    área proibida no furo da trava, roteamento pelo Freerouting e DRC.
    - As três placas saem com DRC limpo (0 violações, 0 ligações faltando).
    - Barra do polegar com switches girados 180°: o pino 2 ficava a 0,28 mm
    da borda de trás.
    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
    [coluna_1u.kicad_pcb, coluna_2u.kicad_pcb, placa_L.kicad_pcb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]
2026-09-30 Metade esquerda num arquivo só (assemble.py) e placas centralizadas na folha
    - assemble.py junta placa L + 3 colunas 1u + coluna 2u na posição do CAD
    (ortho e stagger 150%), com as redes reais da matriz; os jumpers viram
    linhas de ligação. As 34 ligações pendentes batem com o barramento.
    - route.py centraliza cada placa na folha A3; a prévia alinha pelo contorno.
    [coluna_1u.kicad_pcb, coluna_2u.kicad_pcb, metade_esquerda.kicad_pcb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]
2026-09-30 Metade esquerda: placas afastadas 8 mm para ver onde cada uma acaba
    [metade_esquerda.kicad_pcb, metade_esquerda_150.kicad_pcb]
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2026-09-30 LED RGB por tecla, mão direita e teclado inteiro num arquivo
    - LED RGB SK6812MINI-E em cada tecla Choc (38 + 35), na janela do Choc;
    diodos vão para o canto noroeste; capacitor de 4,7 uF por placa.
    - Jumper de 13 vias (linhas, colunas, VLED, GND, DAT) em blocos 2 x 7,
    J_IN e J_OUT em alturas diferentes; cabeçalho da placa L com 20 pads.
    - Mão direita: placa_L_dir (8 teclas 1u + shift 2u; barra com espaço,
    return, cmd e 4 setas táteis TS-1187A), coluna_1u_dir, coluna_2u_dir.
    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
    [coluna_1u.kicad_pcb, coluna_1u_dir.dxf, coluna_1u_dir.kicad_pcb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]
2026-09-30 Rev1: plano e CAD com a placa MCU na cunha, USB-C atrás e conector magnético
    - Com estabilizador nas teclas de 2u, o MCU sai da placa L: placa MCU
    própria na cunha (x 1,5-18,5, y 46-106,5), MDBT50Q com a antena na
    borda externa, USB-C na face de trás.
    - Flex de 20 vias por um rasgo no bloco fixo, no chassi e na bandeja
    (x 1,5-13, y 68,6-70), fora do curso da placa-came.
    - Conector pogo magnético de 5 pinos na face da bandeja (a barra tem só
    3 mm); saem os 4 pogo e o furo antigo da bateria.
    - Verificação de colisões: tudo vazio em 0 e 150% (incluindo mcub_parts
    e magc, novas).
    - hardware/pcb/rev1.md com decisões, posições, pinos e o que falta fechar.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
    [yggi_v3.scad]
2026-09-30 App do Yggi: núcleo em Rust + app SwiftUI para macOS com teclado simulado
    Trabalho da conversa "Criar o app em Swift para controlar o Yggi":
    núcleo Rust (modelo, layout, simulador, estatísticas, iluminação) exposto ao
    Swift via UniFFI, app de barra de menus e janela principal (visão geral,
    teclas, luzes, estatísticas), docs/app.md com as decisões e .gitignore para
    os artefatos de build.
2026-09-30 Barra de menus em abas com widgets: grade de 3 colunas, 5 tamanhos e editor com arrastar
    O núcleo ganha menubar.rs: catálogo de 16 widgets com os tamanhos aceitos
    (1x1, 2x1, 3x1, 2x2, 3x2), encaixe na grade de 3 colunas, operações de
    edição de abas e widgets e gravação em texto. O popover passa a mostrar as
    abas, e a janela ganha a seção Barra de menus para montar tudo arrastando.
2026-09-30 Marca do Yggi, ícone do app e ícone da barra que mostra o estado do teclado; stagger e brilho de 0 a 100%
    - docs/brand: marca (três cápsulas em Y), versão branca, contorno, assinatura e ícone do app.
    - Núcleo: brand.rs desenha a marca em cápsulas e escolhe a pose do ícone da barra
    (braços abertos com stagger, lados afastados e haste dividida com metades
    separadas, haste curta com bateria baixa, contorno quando desconectado).
    - Barra de menus: só o ícone, sem porcentagem.
    - App: AppIcon gerado do SVG (scripts/make-icons.swift).
    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
2026-09-30 Corrige o ícone da barra que não mudava e a janela cortada
    - AppDelegate.shared lia NSApp.delegate, que com o SwiftUI é outro objeto: a
    animação do ícone e os botões do balão não achavam o AppDelegate.
    - A janela respeita o tamanho mínimo das telas (sizingOptions .minSize) e o
    editor da barra de menus ficou mais estreito; antes o SwiftUI cortava as bordas.
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2026-09-30 Testes contra regressões, verificações da camada Swift, CI e documento de arquitetura
    Núcleo:
    - tests/arquitetura.rs: cada módulo só usa as camadas de baixo; módulos puros sem
    travas, threads nem relógio.
    - tests/marca.rs: os SVGs de docs/brand batem com yggi_mark.
    - keyboard_shape: a geometria do teclado simplificado sai do núcleo (o mapa de calor
    tinha um vão de 1u entre as metades juntas por refazer a conta em Swift).
    - Teste com 20 sementes x 300 edições aleatórias da barra de menus. Achou um bug:
    next_id não era gravado, e ids de widgets apagados voltavam depois de reabrir.
    - rustfmt.toml, clippy sem avisos, toolchain fixa (rust-toolchain.toml).
    Swift:
    - Yggi --veri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
